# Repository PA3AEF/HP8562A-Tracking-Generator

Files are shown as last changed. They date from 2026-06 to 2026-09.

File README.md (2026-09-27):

# Tracking Generator for the HP 8562A/B Spectrum Analyzer  
**Reconstructing the Analyzer’s RF Sweep from Its Local Oscillator**
**A modular, analyzer‑synchronous architecture**

---

## What this project is

The HP 8562A/B spectrum analyzer does not include a tracking generator.  
However, it exposes enough of its internal LO system to build one externally.

This project implements a **modular, sweep‑synchronous Tracking Generator (TG)** that behaves as if it were a native part of the HP 8562A/B.  
It reconstructs the analyzer’s RF sweep using only:

- 1st LO Output (about 3.9–6.8 GHz)  
- LO Sweep Output (0–10 V, 0.5 V/GHz)  
- 10 MHz reference

The TG becomes a slave to the analyzer’s LO system and rebuilds the RF sweep in real time across multiple microwave bands.

---

## Why build a Tracking Generator for the HP 8562A/B?

The HP 8562A/B is a legendary instrument: fast, sensitive, and extremely stable.  
But without a tracking generator, it cannot perform:

- filter alignment  
- cavity tuning  
- antenna measurements  
- scalar network analysis  
- frequency response characterization  

This project fills that gap with a TG that follows the analyzer sweep exactly, using the analyzer’s own LO architecture.

---

## How the analyzer sweeps — and how the TG reconstructs the RF

The HP 8562A/B does not sweep an RF source.  
It sweeps its **first local oscillator** and mixes incoming signals down to a fixed IF.  
To cover 1 kHz–26 GHz, it uses **automatic harmonic mixing**, where each RF band uses a different harmonic of the LO:

| RF Band | Harmonic n | IF | LO Formula |
|---:|:---:|---:|---|
| 1 kHz–2.9 GHz | 1 | 3.9107 GHz | LO_SA = RF_SA + 3.9107 GHz |
| 2.75–6.46 GHz | 1 | 310.7 MHz | LO_SA = RF_SA + 0.3107 GHz |
| 5.86–13.0 GHz | 2 | 310.7 MHz | LO_SA = (RF_SA + 0.3107 GHz) / 2 |
| 12.4–19.7 GHz | 3 | 310.7 MHz | LO_SA = (RF_SA + 0.3107 GHz) / 3 |
| 19.1–26.0 GHz | 4 | 310.7 MHz | LO_SA = (RF_SA + 0.3107 GHz) / 4 |

For each band, the analyzer follows: `n * LO_SA = RF_SA + IF`

Because **n changes with band**, the analyzer LO becomes **non‑linear** with respect to the displayed frequency.

A tracking generator must compensate for this non‑linearity to stay aligned.

---

## How the TG reconstructs the analyzer RF

The TG uses the analyzer LO_SA (or a harmonic of it) as the primary LO and subtracts a fixed IF to recreate the analyzer’s RF:

```
RF_TG = (n * LO_SA) – IF_TG
```

Where:

- IF_TG = 310.7 MHz (fixed for all microwave TG modules)  
- n = analyzer harmonic mode for that band  

This yields:

- Base‑Band (n = 1):  
  RF_TG = LO_SA – 3.9107 GHz

- 6 cm (n = 1):  
  RF_TG = LO_SA – 0.3107 GHz

- 3 cm (n = 2):  
  RF_TG = (2 × LO_SA) – 0.3107 GHz

- 12 mm (n = 4, concept):  
  RF_TG = (4 × LO_SA) – 0.3107 GHz

This architecture reqires **no swept PLLs** in the microwave TG modules.  
Sweep coherence comes entirely from the analyzer LO.

---

## High‑level TG architecture

The TG system is composed of modular RF boards:

- **MCU board:**  
  Reads sweep voltage, computes RF_SA for calibration, programs PLLs

- **RF SA‑LO Distribution board:**  
  Conditions and splits the analyzer’s 1st LO to all TG modules

- **Base‑Band TG module:**  
  0–2.9 GHz (uses MAX2870)

- **6 cm TG module:**  
  4.4–6.4 GHz (LO_SA direct, IF_TG = 310.7 MHz)

- **3 cm TG module:**  
  9.5–11.5 GHz (LO_SA ×2, IF_TG = 310.7 MHz)

- **12 mm TG module (concept):**  
  22–26 GHz (LO_SA ×4, IF_TG = 310.7 MHz)

Conceptually:

```
Analyzer → LO Distribution → TG Modules → RF Outputs
Analyzer → 10 MHz → PLLs
Analyzer → V_sweep → MCU → Harmonic modules
```

Each TG module reconstructs the analyzer RF at its own band using a mixer‑based architecture.

---

## TG coverage limits

- **Implemented TG bands:**  
  - Base‑Band (0–2.9 GHz)  
  - 6 cm (4.4–6.4 GHz)  
  - 3 cm (9.5–11.5 GHz)

- **Conceptual / future TG bands:**  
  - 12 mm (22–26 GHz)

- **Analyzer coverage:**  
  - Up to 26 GHz with Option 026  
  - TG coverage currently ends at 11.5 GHz

---

## Repository structure

```
/docs/architecture
    01-tg-system-architecture.md
    02-lo-architecture.md
    03-analyser-lo-internals.md
    04-rf-sa-lo-distribution.md
    05-baseband-module.md
    06-6cm-module.md
    07-3cm-module.md
    08-12mm-module.md
/docs/architecture/images
    architecture diagrams
/firmware
    MCU firmware (Raspberry Pi Pico)
    overview
    images
/hardware/<module>
    schematics, layouts, BOMs, images
/mechanical
    enclosures, front panels
/usage
    calibration and measurement tools
```

---

## Status (Sep 27, 2026)

Checkout the [discussion section](https://github.com/PA3AEF/HP8562A-Tracking-Generator/discussions) for updates on the first results I have. 

- File: [example S21 3 cm lossy filter](./images/s21-3cm-lossy-filter.jpg)
- File: [example S11 3 cm pole filter](./images/s11-3cm-pole-filter.jpg)
- MCU board: 
  - concept tested OK, new PCB in development to accomodate new 10 MHz distribution architecture
  - firmware tested OK. Waiting for final PCB to start polish and publish
- LO Distribution: finished 
- Base‑Band module: finished  
- 3 cm module: proof of concept tested OK (tracking at 10 GHz with 2 GHz span)  
- 6 cm module: architecture defined  
- 12 mm module: conceptual design complete  

---

## License

MIT License.  
See `LICENSE` for details.

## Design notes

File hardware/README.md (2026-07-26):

# Hardware — TG Project

This directory contains all hardware designs for the modular Tracking Generator (TG).  
Each RF module is fully self‑contained with its own schematic, PCB if applicable, and data on on read-made building-blocks.

The hardware is organized into four primary modules:

- **Baseband Module (0–2.9 GHz)**
- **6 cm Module (4.4–6.4 GHz)**
- **3 cm Module (8.5–11.5 GHz)**
- **LO Module (Isolation and distribution of 1st LO from SA)**

All PCBs are designed in KiCad and stored in separate subdirectories.

---

## Directory Structure

Each module directory contains:

- **`schematic.pdf`** — complete schematic  
- **`pcb/`** — KiCad PCB files, 3D views, fabrication output  
- **`bom.csv`** — Bill of Materials  
- **`readme.md`** — module‑specific documentation (gain budget, design notes, test plan)

---

## Hardware Module Overview

### **Baseband Module (0–2.9 GHz)**
- IF chain from the HMC219 downconverter
- PLL at 3.9107 GHz  
- 3 GHz low‑pass filter  
- Pads, IF amplifier, SMA output  

### **6 cm Module (4.4–6.4 GHz)**
- HMC220 mixer  
- IF and RF amplification  
- Band‑pass filtering for 4–8 GHz  
- Purpose: upconversion for the 6 cm tracking generator band

### **3 cm Module (9.5–11.5 GHz)**
- HMC220 mixer 
- PLL at 310.7 MHz
- Band-pass filter at 310 MHz 
- High‑frequency RF amplifier (9–12 GHz)  
- Band‑pass filtering for 8–12 GHz  
- Purpose: upconversion for the 3 cm tracking generator band

### **Control Module**
- Raspberry Pi microcontroller
- Control of all circuitry, indicators, etc.
- Power provision for each band module (5-12V selectable) 
- Prper startup-shutdown sequence for band switching
- 10 MHz reference input buffering and distribution (SMA)
- SPI control for PLLs 

### **LO Module**
- Isolation of 1st LO output of analyser
- Braodband amplification of 1st LO output
- Distribution of 1st LO to band modules 

---

## Design Principles

- **Modular:** each RF module is electrically and mechanically independent  
- **SMA‑based:** all interconnects use SMA cables for clean, predictable RF paths  
- **Reproducible:** BOMs, schematics, and PCB files are fully documented  
- **RF‑optimized:** short signal paths, solid grounding, controlled impedance  
- **Measurable:** each module includes clear test points and a documented gain budget

---

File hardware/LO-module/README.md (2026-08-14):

# LO Module — External 1st LO Distribution

The LO Module takes the **1st LO output from the HP 8562A/B Spectrum Analyzer** and distributes it cleanly and at controlled power levels to all TG RF modules.  
The module provides isolation, optionally gain compensation, RF switching, and MCU‑based band selection.

---

## Purpose

- Accept the **external 1st LO** (3.9–6.8 GHz, ~16.5 dBm) from the HP8562A/B  
- Provide **3.5–7 GHz isolation** to protect the analyzer and stabilize the LO feed  
- Apply **~10 dB broadband gain** to compensate for PE42540 switch losses  
- Route the LO to **four isolated SMA outputs**  
- Allow **MCU‑controlled band selection** via PE4250/PE42540 RF switches  
- Deliver **~+16 dBm** per‑port LO drive for mixers in each TG band module

---

## Block Diagram

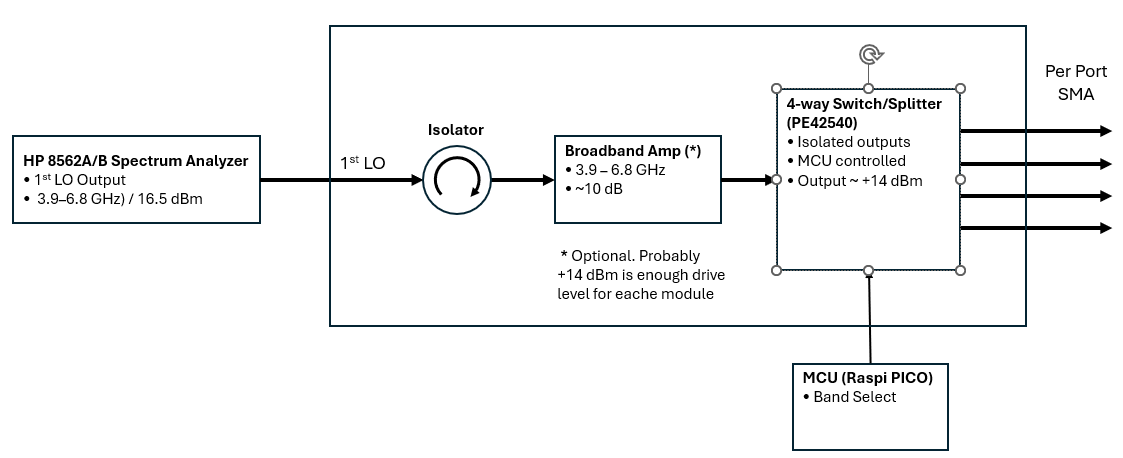
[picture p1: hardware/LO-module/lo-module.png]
TG system architecture


---

## LO Signal Path

### 1. 1st LO Input
- Source: HP 8562A/B Spectrum Analyzer  
- Frequency: **3.9–6.8 GHz**  
- Power: **~16.5 dBm**  
- Input is routed directly into the isolator to protect the analyzer and stabilize impedance.

### 2. Isolator (3.5–7 GHz)
- Ensures reverse isolation  
- Prevents reflections from the TG system  
- Provides a stable load to the analyzer’s LO output

**NOTE:** A broad amplifier can be used instead. It would give enough isolation too. 

### 3. Broadband Amplifier (~10 dB) (optional)
- Frequency range: **3.9–6.8 GHz**  
- Purpose: compensate insertion loss of RF switch  
- Ensures final per‑port LO level remains at **~+16 dBm**

**NOTE:** Various solutions can be used to create a 4-way switch/splitter. WIth the low-loss PE42540 it is not necesary

### 4. PE42540 4‑Way RF Switch/Splitter
- Provides **four isolated LO outputs**  
- MCU‑controlled switching  
- Low insertion loss  
- Output level per port: **~+16 dBm**

### 5. SMA Outputs
- One SMA per band module  
- Clean, isolated LO feed  
- Stable drive level for mixers

### 6. MCU Control (Raspberry Pi Pico)
- Controls PE42540  
- Selects active LO output path  
- Provides band‑select logic for TG modules

---

## Design Notes

- LO drive target: **~+16 dBm** at each SMA  
- Isolator ensures analyzer protection and stable LO impedance  
- Broadband amp compensates switch losses and maintains output power  
- PE42540 chosen for isolation and MCU‑controlled routing  
- Maintain short RF traces and controlled impedance routing

---

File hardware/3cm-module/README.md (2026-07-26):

# 3 cm Tracking Generator Module (9.5–11.5 GHz)

The 3 cm module is the harmonic‑mode RF upconversion stage of the Tracking Generator.  
It reconstructs the analyzer’s 9.5–11.5 GHz sweep by combining:

- the analyzer’s 1st LO (LO_SA = 4.905–5.905 GHz)  
- the analyzer’s internal IF = 310.7 MHz (harmonic 2 mode)  
- a TG‑generated IF_TG = 310.7 MHz from an ADF4351  
- a doubled version of the analyzer’s 1st LO (LO₂ = 9.81–11.81 GHz) for the HMC220 mixer

All frequencies remain coherent with the analyzer because they are derived from the analyzer’s 1st LO and 10 MHz reference.

---

## Harmonic‑mode coherence

In the 3 cm band, the HP 8562A/B uses **2× harmonic mixing** with an internal IF of **310.7 MHz**.

The analyzer’s 1st LO follows:  
`2 × LO_SA = RF_SA + 310.7 MHz`  →  `LO_SA = (RF_SA + 310.7 MHz) / 2`

For RF_SA = 9.5–11.5 GHz, this yields:  
`LO_SA = 4.905–5.905 GHz`

This is the actual LO range the 3 cm TG module must track.

---

## Why the LO must be doubled

The HMC220 mixer requires:

- IF port: DC–4 GHz  
- LO/RF ports: 5–12 GHz  

The analyzer’s 1st LO (4.905–5.905 GHz) is too low for the HMC220 LO port.  
Therefore, the TG uses a ×2 multipiler (HMC204): `LO₂ = 2 × LO_SA = 9.81–11.81 GHz`, fitting the mixer’s LO range.

---

## IF_TG generation (ADF4351)

The TG generates a fixed IF signal using the ADF4351: `IF_TG = 310.7 MHz`.  
The MCU programs the ADF4351 via SPI and maintains sweep coherence with the analyzer’s 10 MHz reference.
A Band Pass Filter at 310 MHz follows the ADF4351 to maintain signal purity. 

---

## Mixer output and TG coherence

The HMC220 mixer produces: `RF_TG = LO₂ – IF_TG = RF_SA`  
Substituting the ranges:  
LO₂ = 9.81–11.81 GHz, IF_TG = 310.7 MHz → RF_TG = 9.5–11.5 GHz.  
This exactly matches the analyzer’s displayed frequency.

---

## Module architecture and building blocks

### HMC204 Analyzer LO doubler
- Input: LO_SA = 4.905–5.905 GHz  
- Output: LO₂ = 9.81–11.81 GHz  
- Purpose: shift analzer LO into HMC220 LO range while maintaining sweep coherence

### ADF4351 IF_TG generator
- Output: 310.7 MHz (fixed)  
- MCU‑controlled and reference‑locked  
- Purpose: provide the IF offset needed to reconstruct RF_TG

**HFSS modeling results optimized for standard LC values:** 

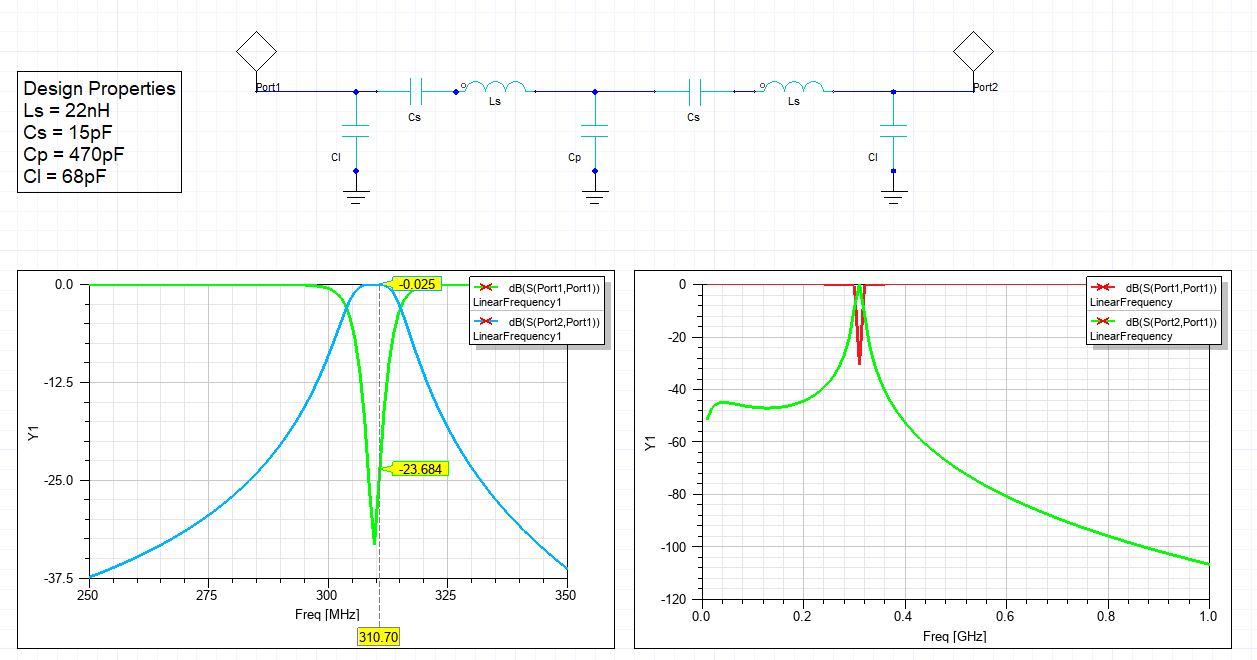
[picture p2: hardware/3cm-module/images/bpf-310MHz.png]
310 MHz BPF


### HMC220 mixer
- LO port: 9.81–11.81 GHz  
- IF port: 310.7 MHz  
- RF port: 9.5–11.5 GHz  
- Purpose: perform the upconversion that produces the 3 cm TG output

### Band‑pass filter (8–12 GHz)
- Removes LO₂ leakage, IF_TG leakage, and mixer images  
- Ensures only the 9.5–11.5 GHz band reaches the amplifier

Did not succeed yet in modeling a proper BPF so, for now a simple lowpass filter on 0.8mm FR4. 

**HFSS modeling results for a stepped impedance lowpass filter:** 

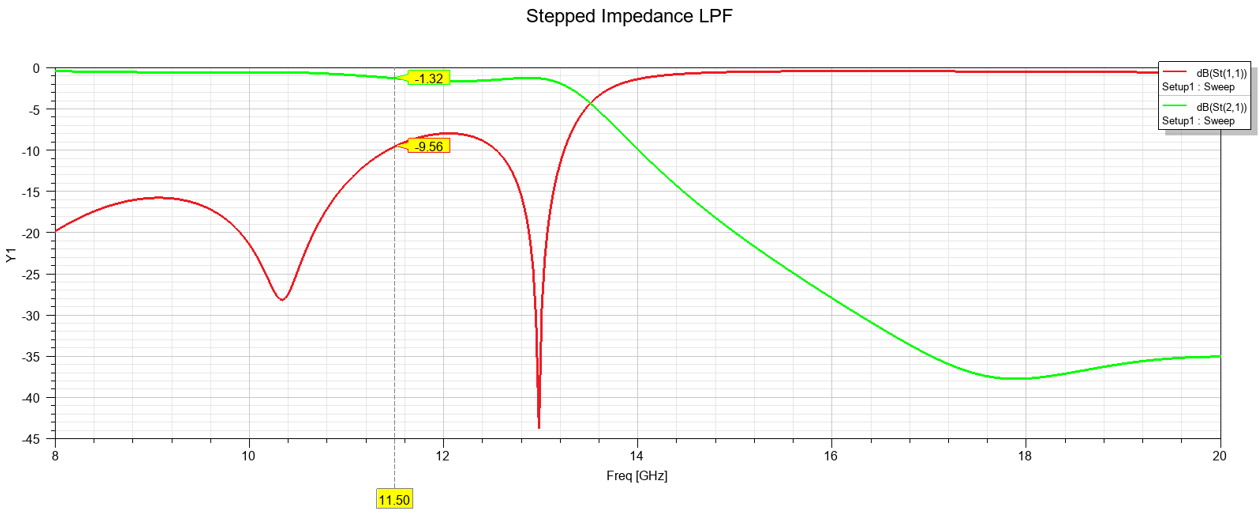
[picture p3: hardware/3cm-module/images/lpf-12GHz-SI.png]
12 GHz LPF stepped impedance


### RF gain stage + output pad
- Provides ~0 dBm output  
- Maintains linearity across the sweep  
- Ensures stable 50 Ω output at the TG output SMA connector

---

## Performance targets

### Frequency performance
- Output band: 9.5–11.5 GHz  
- Must track analyzer sweep exactly  
- Fast settling to follow analyzer sweep speed

### Amplitude performance
- Target output: ~0 dBm  
- Flatness corrected at system level  
- No compression across sweep

### Spectral purity
- Low LO₂ leakage  
- Low IF_TG leakage  
- Spurs dominated by ADF4351 + multiplier chain  
- Phase noise dominated by analyzer LO

### Implementation constraints
- RF layout suitable for >10 GHz  
- Isolation between LO₂, IF_TG, and RF paths  

---

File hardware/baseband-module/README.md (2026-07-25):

# Base‑Band Tracking Generator Module  
**(0–2.9 GHz fundamental‑mode section)**

The Base‑Band module generates the 0–2.9 GHz portion of the Tracking Generator output.  
It uses the analyzer’s 1st LO as the swept RF input and mixes it with a locally generated LO_TG to recreate the analyzer’s RF sweep at the TG output.

This module contains the **core RF building blocks** for fundamental‑mode operation:

- clean LO_TG generation  
- LO driver amplification  
- fundamental mixer  
- post‑mix filtering  
- output leveling  

All signals remain coherent with the analyzer because the MAX2870 locks to the analyzer’s 10 MHz reference.

---

## Module Overview

The Base‑Band module consists of the following RF chain:

1. **Analyzer 1st LO input from the LO Distribution module**  
2. **MAX2870 PLL generating LO_TG (fixed 3.9107 GHz)**  
3. **LO driver amplifier (20 dB gain)**  
4. **LO band‑pass filter + pad**  
5. **Fundamental mixer (HMC219)**  
6. **Low‑pass filter (DC–3 GHz)**  
7. **Output pad (level trim)**

Each block is described below.

---

## Building Blocks (LO_TG path)

### MAX2870 PLL / LO_TG Source
- Generates the fixed LO_TG required for fundamental mixing.  
- Locked to the analyzer’s 10 MHz reference for coherence.  
- Output level is low (programmable -4 dBm to +5 dBm) and requires external amplification.  
- Ready‑made MAX2870 modules with SPI and SMA connectors work well

---

### LO Driver Amplifier (3.9 GHz)
- Raises the MAX2870 output to proper mixer‑drive levels.  
- Provides stable gain and low added phase noise.  
- Offers isolation between the PLL and the mixer LO port.  
- A boxed 20 dB gain module with SMA I/O is ideal.

---

### LO Band‑Pass Filter (3.9107 GHz) + Pad
- Cleans up PLL and amplifier spurs.  
- Ensures a spectrally clean LO_TG at the mixer.  
- Final pad sets the LO level to ~13 dBm at the HMC219 LO pin.  
- Ready‑made BPF modules with SMA I/O work well, but DIY can perform equally well

---

## Mixer and Output Path

### Fundamental Mixer (HMC219)
- Core element of the Base‑Band module.  
- RF port: analyzer 1st LO (3.9–6.8 GHz)  
- LO port: LO_TG (~13 dBm)  
- IF/RF output: 0–2.9 GHz TG signal  
- Requires good grounding and shielding to minimize LO feedthrough.  
- Ready‑made boxed modules very much simplify construction.

---

### Low‑Pass Filter (DC–3 GHz)
- Removes mixer images and LO leakage.  
- Defines the usable Base‑Band TG output range.  
- Should have low insertion loss and strong stop‑band rejection.  
- DIY CNC‑boxed LPF is fine; ready‑made modules also work.
- Optional pad trims the output to 0 dBm.

**HFSS modeling results optimized for standard LC values:**
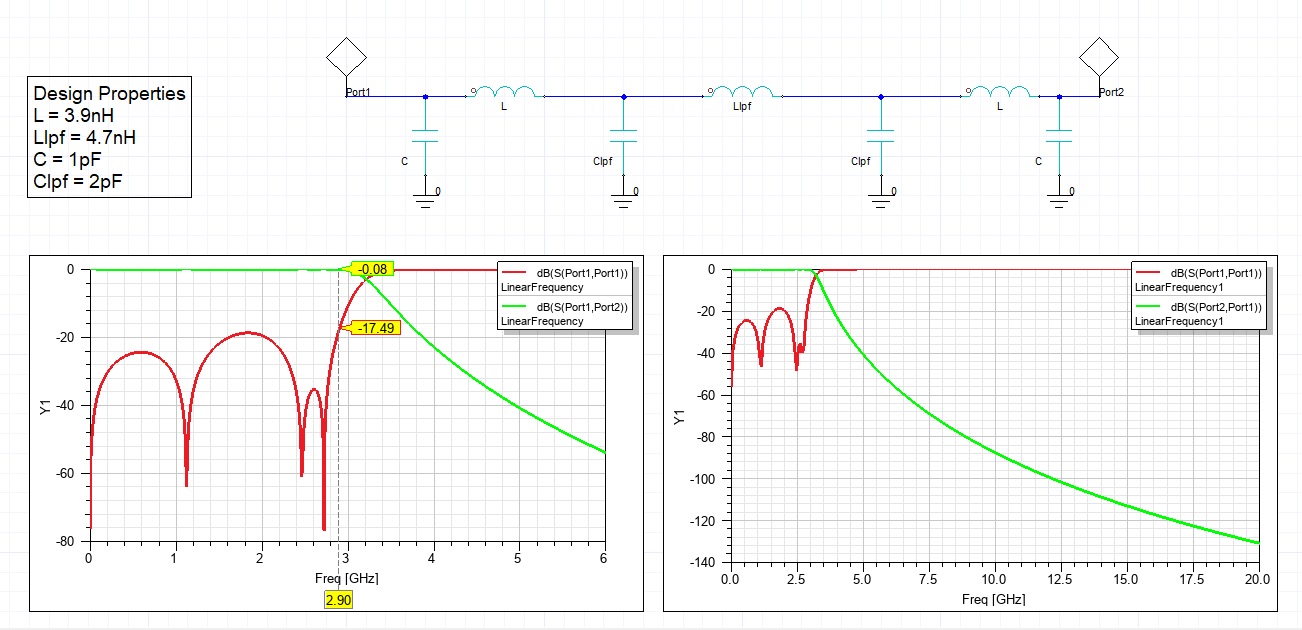
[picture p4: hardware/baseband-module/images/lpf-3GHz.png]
Low Pass Filter with Fc 3 GHz


Another solution was modeled using folded stepped impedance open subs after Makki et al. 

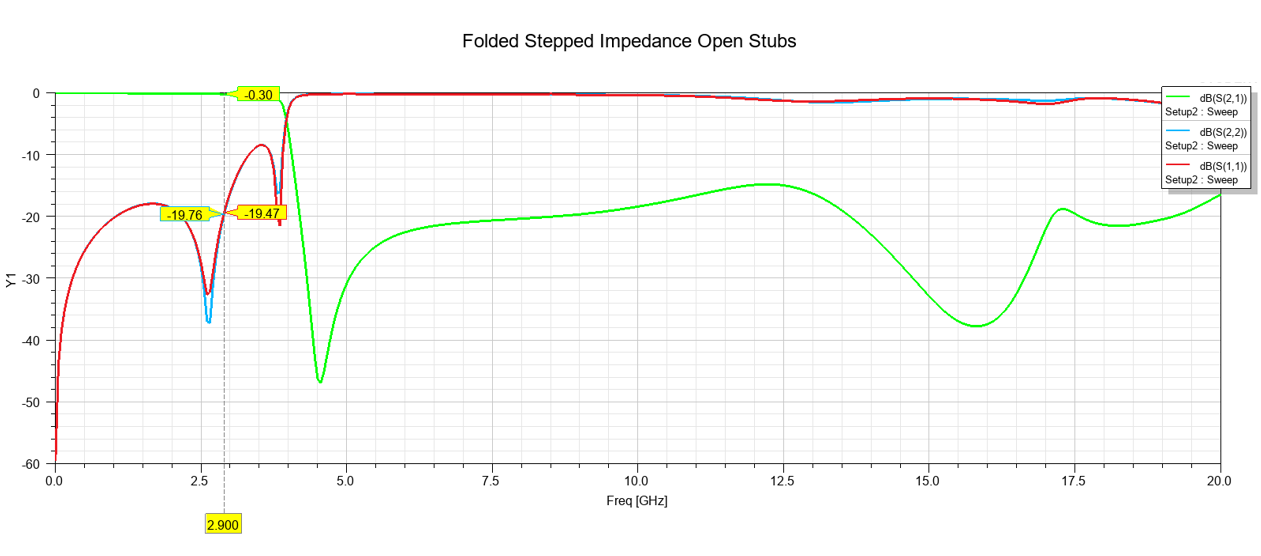
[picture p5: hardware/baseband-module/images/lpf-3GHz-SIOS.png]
Low Pass Filter with Fc 3 GHz on Microstrip


---

## Performance Goals

### Frequency Tracking
- Output range: 0–2.9 GHz  
- Must follow analyzer sweep exactly  
- Settling must match analyzer sweep speed

### Amplitude Performance
- Target output: ~0 dBm  
- Flatness corrected at system level  
- Avoid compression in the LO driver and mixer

### Spectral Cleanliness
- Low LO leakage  
- Low mixer images  
- Spurs dominated by PLL  
- Phase noise dominated by analyzer LO

### Implementation Notes
- RF‑clean routing up to 3 GHz  
- Strong isolation between LO_TG and RF paths  

---

## Summary

The Base‑Band module is straightforward once broken into functional blocks.  
Each block (PLL, LO driver, mixer, filters, pads) can be built and tested independently.
Many blocks are ready-made available.

---

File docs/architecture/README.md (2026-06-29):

# Documentation Index

---

## System Architecture

### 01 TG System Architecture  
File: [01-tg-system-architecture.md](./01-tg-system-architecture.md) 
High‑level description of the complete Tracking Generator system: module roles, signal flow, LO distribution, and control architecture.

---

## Local Oscillator Architecture

### 02 - LO Architecture  
File: [02-lo-architecture.md](./02-lo-architecture.md)
Detailed explanation of how all LOs are derived from the analyzer’s 1st LO and 10 MHz reference, including per‑band LO strategies.

---

## Analyser Local Oscillator Internals

### 03 - Analyser LO Internals
File: [03-analyser-lo-internals.md](./03-analyser-lo-internals.md)
Explain how the HP 8562A/B analyzer generates the 4.905–5.905 GHz 1st LO range used by the Tracking Generator.

---

## LO Distribution Hardware

### 04 - RF SA‑LO Distribution  
File: [04-rf-sa-lo-distribution.md](./04-rf-sa-lo-distribution.md)
Design and function of the LO distribution module that conditions, isolates, and splits the analyzer’s 1st LO to al TG modules.

---

## TG Modules

### 05 - Base‑Band TG Module (0–2.9 GHz)  
File: [05-base-band-module.md](./05-base-band-module.md)
Architecture and implementation of the fundamental‑mode TG module.

### 06 - 6 cm TG Module (4.4-6.4 GHz)  
File: [06-6cm-module.md](./06-6cm-module.md)
Architecture and implementation of the 6 cm harmonic‑mode TG module.

### 07 - 3 cm TG Module (9.5–11.5 GHz)  
File: [07-3cm-module.md](./07-3cm-module.md)
Architecture and implementation of the 3 cm harmonic‑mode TG module.

### 08 - 12 mm TG Module (concept)  
File: [08-12mm-module.md](./08-12mm-module.md)
Architecture and implementation of the 12 mm harmonic‑mode TG module.

---

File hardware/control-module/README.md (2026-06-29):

# Control Module — MCU and 10 MHz Reference Buffer (Hardware)

Compact hardware overview for the Control Module: power sequencing, protection, MCU host interfaces, and the low‑noise 10 MHz reference buffering and 1:4 distribution. Detailed hardware-level descriptions for the **10 MHz reference** and **MCU** are in separate documents (`docs/10MHz_reference.md`, `docs/mcu-hardware.md`). Firmware is covered elsewhere.

---

## Purpose

- Buffer and distribute an external **10 MHz reference** to **4 isolated outputs**  
- Provide MCU-host hardware: power, programming, debug, and physical control interfaces  
- Protect and condition reference and power inputs (ESD, TVS, reverse polarity)  
- Present SPI/UART/USB headers and status indicators for system integration

---

## Block Diagram

10 MHz Ref In → Input Protection → Low‑noise Buffer → 1:4 Splitter/Switch → Output Buffers → **4 × SMA REF OUT**  
Power In → Sequencing & Regulators → MCU + Peripherals  
MCU headers: SPI, UART, VRef, Switch, RF-Modules

---

## Hardware Interfaces

- **Reference Input**
  - **SMA** connector with input protection and level detect
  - DC blocking and optional AC coupling upstream of buffer
- **Reference Outputs**
  - **4 × SMA** buffered outputs, individually enabled
  - Target nominal level: **0 dBm** per output (see `docs/10MHz_reference.md`)
- **Control / Comms**
  - **SPI** header (MOSI, MISO, SCLK, CS, GND, Vcc) for downstream PLLs
  - **UART / USB** hardware interface for firmware connectivity
- **Power**
  - External DC input with reverse‑polarity protection
  - Onboard regulators with power‑good signals and sequencing
- **Indicators**
  - Power, module-select and lock detect fault LEDs at PCB headers

---

## Design Notes (Hardware Only)

- **Phase noise:** buffer chosen to add minimal phase noise; layout keeps RF ground continuous under RF chain.  
- **Isolation:** per‑output buffering prevents cross‑talk; outputs terminated and DC‑blocked.  
- **Protection:** input ESD, TVS, and surge protection on REF IN and power rails.  
- **Mechanical:** SMA connectors on PCB edge; keep digital switching components physically separated from RF path.  
- **EMC:** ferrite beads, common‑mode chokes, and local decoupling to reduce digital noise coupling into 10 MHz path.  
- **Test points:** RF amplitude, buffer bias, and power‑good nets exposed for bench verification.

---

## Connector / Pin Summary

- **REF IN:** SMA (10 MHz)  
- **REF OUT 1–4:** SMA buffered outputs  
- **SPI:** 6‑pin header (MOSI, MISO, SCLK, CS, GND, Vcc)  
- **UART/USB:** Micro‑USB or TTL UART header  
- **POWER:** Screw terminal or header;
- **Band Selection:** 3-pin header
- **LO Switch:** 3-pin header
- **RF Modules:** 3-pin and 2-pin headers 

---

## Control Module
 
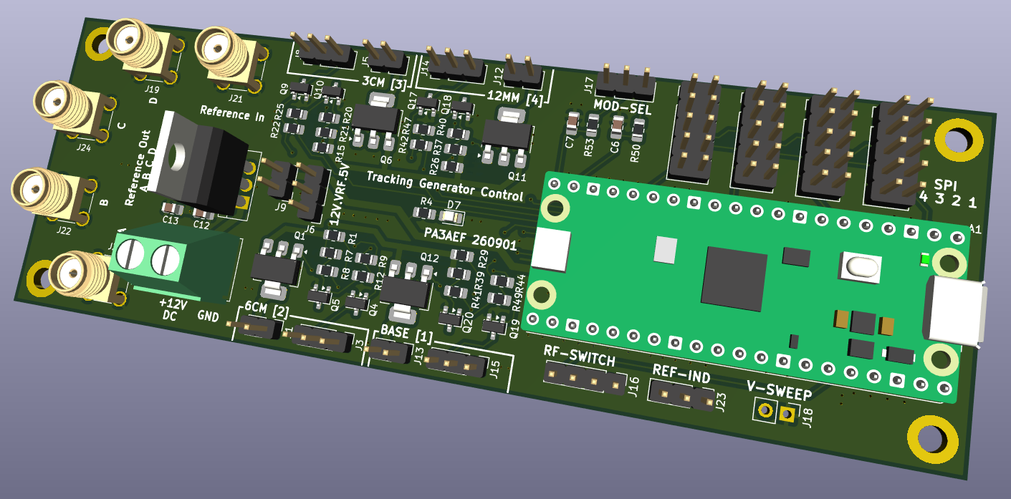
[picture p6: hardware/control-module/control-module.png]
Control Module populated PCB


---

## Documentation

Hardware detail references:  
- **`10MHz_reference.md`** — full schematic, BOM, and RF measurements  
- **`mcu-hardware.md`** — MCU pinout, power sequencing, and debug connectors  
- **`control-module`** — mechanical drawings and test fixtures

---

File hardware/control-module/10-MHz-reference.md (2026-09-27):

# 10 MHz Reference Fan‑Out

The 10 MHz reference distribution network provides a stable, low‑noise signal to multiple subsystems within the control module.  
This revision replaces the earlier op‑amp‑based buffer with a **broadband MMIC amplifier** to achieve higher gain, better impedance control, and improved RF integrity.

---

## Design Intent
The goal is to replicate a single precision 10 MHz reference into several identical outputs while maintaining:

- Consistent amplitude and phase across all outputs  
- True 50 Ω system compatibility  
- Minimal additive noise and distortion  
- Simple, robust implementation suitable for RF PCB layout  

---

## Functional Architecture

The circuit can be viewed as **four functional blocks**:

1. **Input Conditioning**  
   - The incoming 10 MHz reference is terminated and AC‑coupled into a broadband amplifier.  
   - The interface maintains 50 Ω impedance to prevent reflections and loading of the source.  
   - A small detection network monitors the presence of the reference signal and converts it into a DC logic level for indication.

2. **Amplification**  
   - A single MMIC amplifier provides sufficient gain to overcome splitter losses.  
   - The device operates linearly at 10 MHz, ensuring clean reproduction of the reference signal.  
   - Power‑supply filtering and decoupling maintain low noise and prevent modulation of the reference.

3. **Signal Distribution**  
   - The amplifier output feeds a passive multi‑way splitter.  
   - Each branch is impedance‑matched and AC‑coupled to its output connector.  
   - The topology ensures isolation between outputs and preserves amplitude balance.

4. **Reference‑Presence Indicator**  
   - A detector monitors the RF level at the amplifier output and generates a logic signal when the 10 MHz reference is present.  
   - This logic drives a **dual‑color LED** that provides immediate visual feedback:  
     - **Red** indicates that the module is powered but no reference signal is detected.  
     - **Green** indicates that the 10 MHz reference is active and within expected amplitude.  
   - The indicator circuit uses a simple envelope‑detection and transistor‑switching scheme to translate the RF presence into a DC control signal.

---

## Operational Behavior

When power is applied, the indicator initially lights **red**, confirming that the module is energized but awaiting a valid reference.  
As soon as the 10 MHz signal reaches nominal amplitude, the detector transitions to **green**, signaling that the reference is locked and distributed correctly.  
If the reference disappears or drops below threshold, the circuit automatically reverts to red, providing a clear visual cue of signal loss.

---

## Performance Characteristics
- **Gain Margin:** The amplifier compensates for splitter attenuation, maintaining nominal output levels.  
- **Isolation:** Passive resistive topology provides adequate separation between outputs for reference use.  
- **Noise Contribution:** The MMIC adds negligible phase noise compared to the master reference.  
- **Bandwidth:** The design remains stable and flat well beyond 10 MHz, ensuring predictable behavior.  
- **Power Supply:** Operates from a single low‑voltage rail with standard RF decoupling practices.

---

## Implementation Notes
- Short RF paths and continuous ground planes.  
- Via fencing around the amplifier region for stability.  
- Decoupling capacitors close to the device pins.  
- Maintain symmetry in the splitter layout to ensure equal path lengths.  
- AC‑couple all outputs to DC-protect downstream circuits.

---

## Summary
This MMIC‑based fan‑out architecture provides a clean, broadband, and impedance‑controlled distribution of the 10 MHz reference.  
It simplifies the design compared to op‑amp buffers, improves gain margin, and ensures reliable operation across all connected modules.

---

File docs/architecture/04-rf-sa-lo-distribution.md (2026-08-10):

# RF SA‑LO Distribution Module  
**Function:** Conditioning and distribution of the analyzer’s 1st LO  
**Input:** SA 1st LO (3.9–6.8 GHz, ~+16.5 dBm)  
**Outputs:** Four LO feeds to TG modules  
**Target Output Level:** +16 dBm per port (→ +13 dBm at mixer LO pins)

---

## Overview

The RF SA‑LO Distribution module receives the analyzer’s 1st LO and provides a clean, isolated, level‑controlled LO feed to all Tracking Generator modules.

Its responsibilities:

- Protect the analyzer LO port  
- Provide stable impedance and isolation  
- Amplify the LO to compensate for splitter loss  
- Split the LO into four well‑behaved outputs  
- Ensure each module can achieve **+13 dBm at the mixer LO pin**

This board forms the **central LO backbone** for the entire TG system.

---

## Frequency & level plan

### Input  
- SA 1st LO: 3.9–6.8 GHz  
- Typical level: +16.5 dBm  
- Sweep‑synchronous with analyzer RF

### Internal processing  
- Isolator stabilizes return loss and protects the analyzer (a 10dB gain-block would also give enough isolation) 
- Broadband amplifier restores headroom before splitting (probably not necessary with CMOS siwtch such as PE42540)
- Splitter (Wilkinson, relays or MMICs) provides isolation between TG modules  
- Per‑branch pads flatten response and set final level

### Output targets  
Each TG module receives:

- **LO OUT:** +16 dBm nominal  
- After on‑module pad/filter (~3 dB):  
  → **+13 dBm at mixer LO pin**

---

## Block diagram

SA LO distribution architecture

---

## Power budget (nominal)

| Stage | Gain/Loss | Level |
|:---|---:|---:|
| SA 1st LO | — | +16.5 dBm |
| Isolator | –0.5 dB | +16 dBm |
| 4-way split (PE42540) | -1.5 dB | +14.5 dBm |
| TG module LO input | — | +14.5 dBm |
| On‑module pad/filter | –3 dB | **+11 dBm at mixer LO pin** |

---

## Output ports

Four identical LO outputs:

- Base‑Band module  
- 6 cm module  
- 3 cm module  
- 12 mm module  

Each port includes:

- Isolation thru splitter  
- Per‑branch pad  
- 50 ohm matched SMA  
- +16 dBm nominal output

---

## Mechanical / layout notes

- Isolator close to TG input  
- Amplifier and splitter routes short and shielded  
- Clear labeling for all LO outputs  

---

## Future expansion

Designed to support:

- Additional TG modules  
- Higher‑frequency LO distribution  
- Optional per‑branch filtering  
- LO mute switching thru MCU

---

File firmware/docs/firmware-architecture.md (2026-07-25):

# Firmware Architecture HP8562A Tracking Generator

This document describes the modular firmware architecture used in the **HP8562A Tracking Generator** project.  
It complements the system‑level design documents in `/docs/architecture` and focuses on the internal structure, sequencing, and logic of the firmware modules.

---

## 1. Overview

The firmware controls the TG’s mixed‑PLL synthesizer system (MAX2870 + ADF4351), band‑switching logic, and RF routing.  
It is designed for clarity, reproducibility, and modularity, following a clean separation between hardware abstraction and signal‑chain logic.

### Key design goals
- Deterministic band‑switching sequence  
- Unified PLL programming interface  
- Operator‑friendly feedback and debug output  
- Safe RF transitions (no hot‑switching)  
- Extensible for future bands or PLL types  

---

## 2. Directory Structure

/firmware  
  src/  
   • Tracking_Generator.ino
   • pins.h
   • bands.h / bands.cpp
   • pll_max2870.h / pll_max2870.cpp  
   • pll_adf4351.h / pll_adf4351.cpp    
   • pll_control.h / pll_control.cpp  
   • pe42540.h / pe42540.cpp
   • ramp.h / ramp.cpp  
   • rotary.h / rotary.cpp  
   docs/  
   • firmware_architecture.md  

Each module has a single responsibility and can be tested independently.

---

## 3. Module Responsibilities

**pins.h** - Defines all GPIO assignments  
**bands.cpp** - Implements band table, state machine, and switching logic  
**pll_max2870.cpp / pll_adf4351.cpp** - Compute register sets for each PLL type  
**pll_control.cpp** - Holds static default register sets per band  
**pe42540.cpp** - Controls LO routing switch
**ramp.cpp** - Converts ramp ADC value to LO frequency  
**rotary.cpp** - Reads Gray‑code band selector  
**Tracking_Generator.ino** - Initializes modules and runs the control loop  

---

## 4. Band‑Switching Sequence

The firmware follows an eight‑step, RF‑safe switching sequence:

1. Disable old gain block (`PIN RFEN_xx LOW`)  
2. Disable old PLL (`PIN CE_xx LOW`)  
3. Switch LO path (PE42540)  
4. Enable new PLL (`PIN CE_xx HIGH`)  
5. Program PLL registers  
6. Wait for lock (`PIN LD_xx HIGH`)  
7. Enable new gain block (`PIN RFEN_xx HIGH`)  
8. New band active  

### Sequence Diagram  

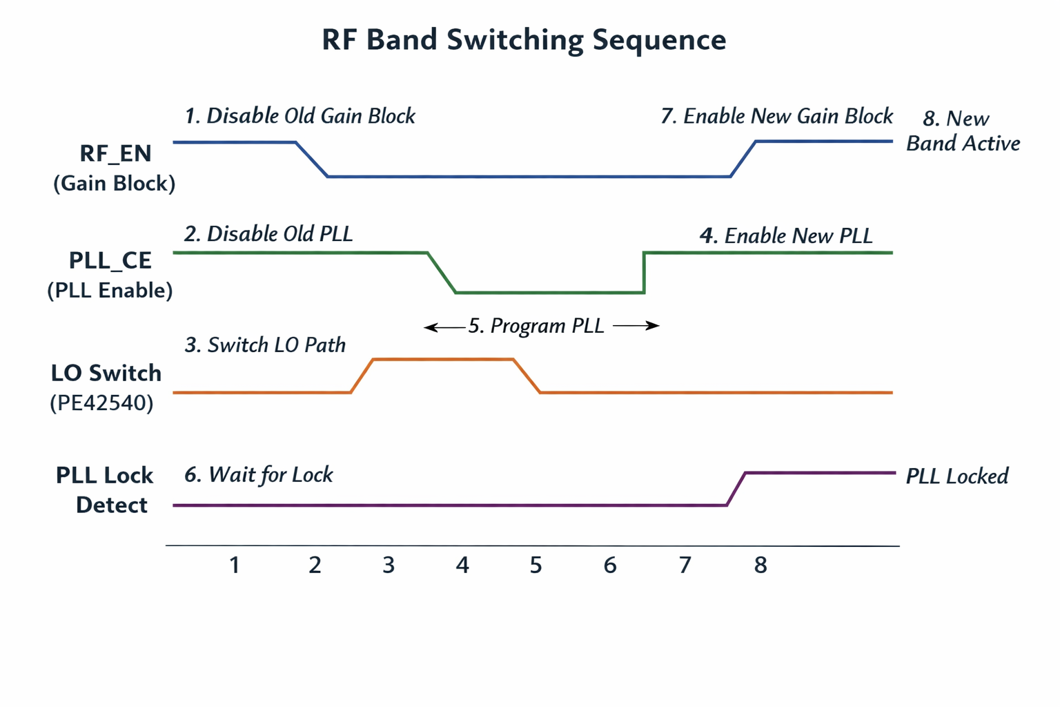
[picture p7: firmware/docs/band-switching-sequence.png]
Band switching sequence


### Timing Diagram  

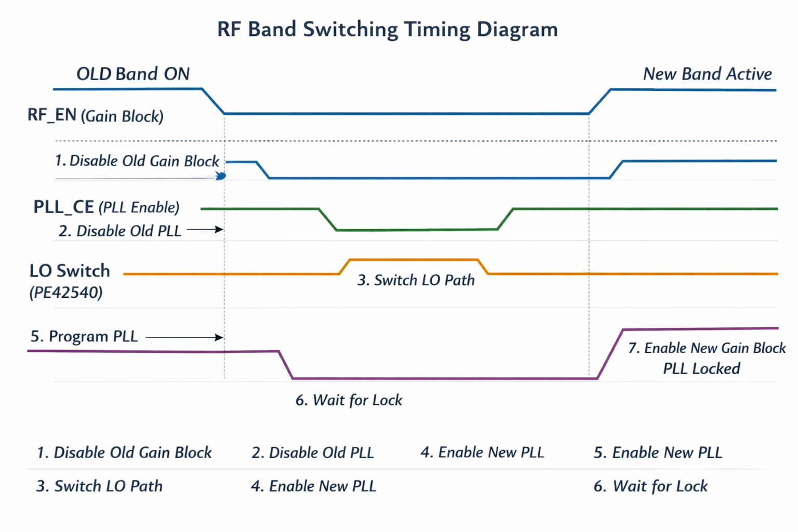
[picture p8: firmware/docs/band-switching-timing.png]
Band switching timing


These diagrams illustrate the relative timing of RF_EN, PLL_CE, LO Switch, and PLL Lock Detect signals.

---

## 5. Safety and Timing Considerations

- RF_EN is always turned off before any LO or PLL transition  
- PLL_CE is toggled only when RF_EN is low  
- PE42540 switching occurs with no RF present  
- PLL lock time is verified before enabling RF output  
- Typical delays:  
  • CE‑to‑SPI start: 500 µs  
  • SPI burst: ~100 µs  
  • Lock wait: 5–10 ms (band‑dependent)  

---

## 6. Build and Deployment

- Platform: Raspberry Pi Pico (RP2040)  
- Toolchain: Arduino RP2040 Core  
- SPI speed: 1 MHz (safe for MAX2870/ADF4351)  
- Serial debug: 115200 baud  
- Upload via USB using Arduino IDE or CLI  

---

## 7. References

- MAX2870 Datasheet  
- ADF4351 Datasheet  
- PE42540 Datasheet  

---

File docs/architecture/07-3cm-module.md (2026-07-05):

# 3 cm Tracking Generator Module  
**RF Output:** 9.5–11.5 GHz (2 GHz span)  
**Harmonic Mode:** n = 2  
**Mixer Core:** HMC220  
**TG IF LO:** ADF4351 (fixed 310.7 MHz)  
**SA LO Path:** Doubled analyzer LO (9.81–11.81 GHz)

---

## Overview

The 3 cm module generates a tracking‑synchronous RF output in the 9.5–11.5 GHz range.  
It operates in the analyzer’s **2× harmonic mixing mode** and derives all timing from:

- **V_sweep**  
- **Analyzer LO_SA** (fundamental synthesizer output)  
- **10 MHz reference**

The module uses:

- A **doubled analyzer LO** as the high‑frequency LO for the HMC220  
- A **fixed‑frequency ADF4351** at 310.7 MHz as the IF LO  
- An HMC220 mixer to produce the final RF output via the difference product

This module forms the primary **X‑band TG path** in the system.

---

## Frequency plan

### Analyzer‑derived quantities  
`RF_SA = 2 * V_sweep`  
`IF_SA = 310.7 MHz`  
`n = 2`

### Analyzer LO (fundamental synthesizer output)  
Harmonic‑mode relation:  
`IF_SA = | 2 * LO_SA – RF_SA |`

Analyzer uses the **high‑side** solution:  
`LO_SA = (RF_SA + 310.7 MHz) / 2`

For RF_SA = 9.5–11.5 GHz:  
`LO_SA = 4.905–5.905 GHz`

This is the **actual analyzer LO** delivered to the TG distribution board.

---

### Doubled LO for HMC220 LO port  
`LO_2 = 2 * LO_SA`  → `9.8107–11.8107 GHz`

This is the **high‑frequency LO** applied to the HMC220 LO port.

---

### TG IF LO (ADF4351)  
Mixer uses:  
`RF_TG = LO_2 – IF_TG = RF_SA`

Since `LO_2 = RF_SA + 310.7 MHz`,  
we require:  
`IF_TG = 310.7 MHz` (constant)

Thus the ADF4351 runs at a **fixed 310.7 MHz**, simplifying control and calibration.

---

## Block diagram

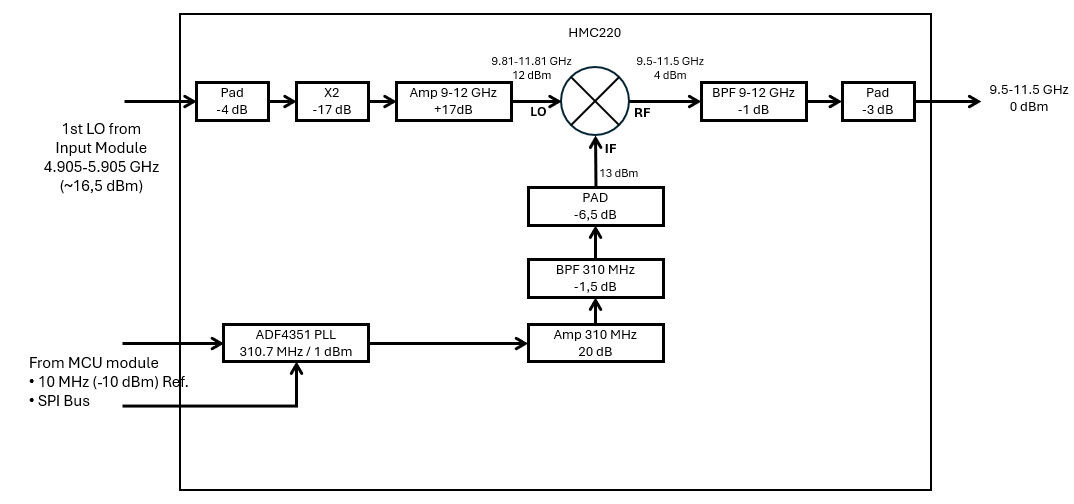
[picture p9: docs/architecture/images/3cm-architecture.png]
3cm TG architecture


```

---

## Power budget (nominal)

| Stage                         | Frequency             | ΔdB     | Level   |
|-------------------------------|----------------------:|--------:|--------:|
| **LO path**                   |                       |         |         |
| SA LO output                  | 4.905–5.905 GHz       |   0 dB  | +16 dBm |
| LO isolator                   | 4.905–5.905 GHz       |  –1 dB  | +15 dBm |
| LO Switch (PE42540)           | 4.905–5.905 GHz       |  -1 dB  | +14 dBm
| LO doubler input              | 4.905–5.905 GHz       |   0 dB  | +14 dBm |
| LO doubler (HMC204)           | 9.81–11.81 GHz        | –17 dB  |  –3 dBm |
| LO amplifier                  | 9.81–11.81 GHz        | +15 dB  | +12 dBm |
| LO at mixer LO port           | 9.81–11.81 GHz        |   0 dB  | +13 dBm |
|                               |                       |         |         |
| **IF path**                   |                       |         |         |
| ADF4351 IF output             | 310.7 MHz             |   0 dB  |  +2 dBm |
| IF filter                     | 310.7 MHz             |  –1 dB  |  +1 dBm |
| IF amplifier                  | 310.7 MHz             | +20 dB  | +21 dBm |
| IF pad (to mixer IF port)     | 310.7 MHz             | –14 dB  |  +7 dBm |
| IF at mixer IF port           | 310.7 MHz             |   0 dB  |  +7 dBm |
|                               |                       |         |         |
| **RF path**                   |                       |         |         |
| Mixer RF out (nominal)        | 9.5–11.5 GHz          |  –8 dB  |  ~5 dBm |
| RF pad / EQ                   | 9.5–11.5 GHz          |  –5 dB  |   0 dBm |
| RF output (SMA)               | 9.5–11.5 GHz          |   0 dB  |   0 dBm |

Levels are nominal and must be trimmed with pads and EQ for flatness over the 2 GHz span.

---

## Control architecture

### Inputs to MCU  
- Band select switch

### MCU responsibilities  
- Program ADF4351 to **fixed 310.7 MHz**  
- Manage LO enable/mute  
- Provide calibration hooks

### SPI layout  
- Shared SPI bus  
- Dedicated CS for ADF4351  
- PLL lock‑detect GPIO

---

## Calibration notes

- Amplitude flatness corrected via output pad/EQ  
- `LO_2` level set by fixed‑gain amplifier  
- ADF4351 spur performance acceptable due to low IF offset  
- No IF sweep required (fixed 310.7 MHz simplifies calibration)

---

## Mechanical / layout notes

- Doubler → LO amp → HMC220 LO path should be short and shielded  
- Good isolation between `LO_2` and RF output  
- ADF4351 IF routing requires clean 50 Ω but is not microwave‑critical  
- Fine‑tune pads for correct levels at `LO_2`, `IF_TG`, and `RF_TG`  

---

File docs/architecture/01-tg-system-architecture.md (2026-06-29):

# Tracking Generator System Architecture  
**Modules:** LO Distribution, Base‑Band, 3 cm, 6 cm (future), 12 mm (future)  
**Coherence Sources:** Analyzer 1st LO, Analyzer 10 MHz reference  
**Architecture:** Distributed mixer‑based TG with per‑band modules  
**Control:** Central MCU (Raspberry Pi Pico)

---

## Overview

The Tracking Generator (TG) system is a modular, analyzer‑synchronous signal source covering:

- **Base‑Band:** 0–2.9 GHz  
- **6 cm:** 4.4-6.4 GHz 
- **3 cm:** 9.5–11.5 GHz  
- **12 mm:** 23-25 Ghz (future)  

All TG modules derive their timing and frequency coherence from the **spectrum analyzer’s internal LO system**, ensuring that the TG output always tracks the analyzer sweep.

Two analyzer signals form the foundation:

- **1st LO** (swept, 3.9–6.8 GHz)  
- **10 MHz reference** (system clock)

The TG system uses these to generate all required LOs for each band.

---

## System‑level signal flow

The TG system is composed of six boards:

1. **MCU (Raspberry Pi Pico)**  
2. **RF SA‑LO Distribution Module**  
3. **Base‑Band TG Module**  
4. **6 cm TG Module**  
5. **3 cm TG Module**  
6. **12 mm TG Module** (future)

The analyzer’s 1st LO enters the system through the **LO Distribution Module**, which conditions and splits it to all TG modules.  
Each TG module then generates its own internal LO(s) and performs mixing to reconstruct the analyzer RF at its target band.

---

## LO architecture summary

### Analyzer 1st LO  
- 3.9–6.8 GHz  
- Sweep‑synchronous  
- Distributed to all TG modules at +16 dBm

### Analyzer 10 MHz reference  
- Shared reference for all PLLs  
- Ensures long‑term coherence

### Base‑Band module  
- Internal IF LO: MAX2870 at 3.9107 GHz (fixed)  
- Mixer: HMC219  
- Output: 0–2.9 GHz

### 6 cm module  
- Internal IF LO: ADF4351 at 310.7 MHz (fixed)  
- Mixer: HMC219
- Output: 4.4-6.4 GHz

### 3 cm module  
- High‑frequency LO: Doubled analyzer LO (8.94–10.28 GHz)  
- Internal IF LO: ADF4351 at 310.7 MHz (fixed)  
- Mixer: HMC220  
- Output: 9.5–11.5 GHz

### 12 mm module (future)  
- Will require higher‑order multiplication  
- Output expected in 23-25 GHz region

---

## Block diagram

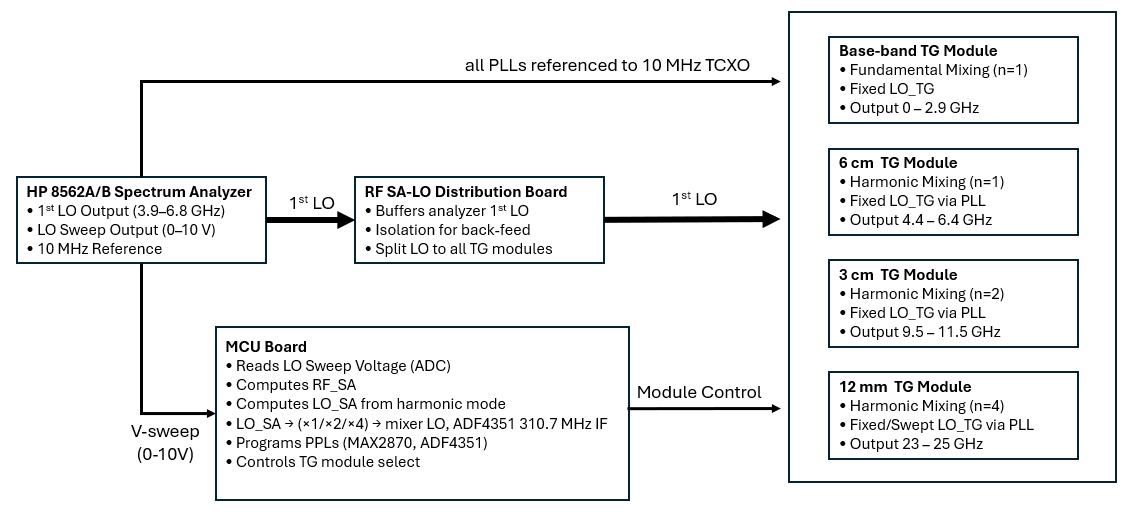
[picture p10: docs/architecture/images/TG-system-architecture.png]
TG system architecture


---

## Power distribution & LO levels

| Path | Level | Notes |
|---|---:|---|
| Analyzer 1st LO → Distribution | +16.5 dBm | Raw analyzer output |
| Distribution → TG modules | +16 dBm | After isolator, amp, splitter, pad |
| TG module LO input | +13 dBm | After on‑module pad/filter |
| TG mixer LO input | +13 dBm | After LO chain |
| Output | 0 dBm | After filters, amp, pad|

All levels are chosen to meet mixer LO drive requirements and maintain isolation.

---

## Control architecture

### MCU responsibilities  
- Program MAX2870 (Base‑Band)  
- Program ADF4351 (6 cm and 3 cm)  
- Compute sweep‑dependent IF if needed 
- Manage LO enable/mute  
- Monitor PLL lock‑detect  
- Handle band selection  

### Shared resources  
- SPI bus shared across all PLLs  
- Dedicated chip‑select per module  
- 10 MHz reference distributed to all PLLs  
- Optional GPIO for LO mute and module enable

---

## Calibration architecture

Each module supports:

- Output level trimming via pads  
- LO drive trimming  
- Mixer conversion‑loss compensation  

System‑level calibration ensures:

- Consistent output level across bands  
- Flatness across each module’s span  
- Coherent phase relationship with analyzer LO

---

## Mechanical / layout considerations

- Analyser LO input at front panel (Cabinet below SA)
- LO Distribution module placed closest to analyzer LO input  
- TG modules arranged to minimize LO crosstalk  
- Shielding around mixers, doublers, and LO amplifiers  
- Consistent grounding across all modules  
- SMA connectors clearly labeled by band  

---

## Future expansion

The architecture is designed to scale to:

- Additional TG bands (e.g. modular RF front-ends with MCU band-descriptor table for LO range, step size, level, etc.) 
- Higher‑order multipliers (e.g. multiplier blocks as seperate modules with additional filters while keeping the PLLs at a comfortable range)
- Optional LO monitoring ports (e.g. directional couplers on LO lines for calibration hooks in the MCU) 
- Optional TG output leveling loops (e.g. per-band detector with digital step attenuators) 
- Optional digital predistortion for flatness correction

All highly ambitious but no roadblocks in the architecture for possible future developmenst . 

---

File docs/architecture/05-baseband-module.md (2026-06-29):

# Base‑Band Tracking Generator Module  
**RF Output:** 0–2.9 GHz  
**Mixer Core:** HMC219  
**TG LO:** MAX2870 at fixed 3.9107 GHz  
**Reference:** 10 MHz from spectrum analyzer  
**Sweep Source:** Analyzer 1st LO

---

## Overview

The Base‑Band module generates a tracking‑synchronous RF output from 0–2.9 GHz.  
It is used for:

- IF chains up to S‑band  
- Wideband filters  
- General‑purpose stimulus-response measurments in the 0–2.9 GHz range

The module uses:

- The analyzer’s 1st LO as the swept input  
- A fixed MAX2870 PLL at 3.9107 GHz  
- An HMC219 mixer  
- A 3 GHz low‑pass filter and output pad

The mixer’s difference product reconstructs the analyzer RF at base‑band.

---

## Frequency plan

### Analyzer RF  
`RF_SA = 0–2.9 GHz`

### Analyzer 1st LO  
`LO_SA = RF_SA + IF_1`  with `IF_1 = 3.9107 GHz`

So:  
`LO_SA = 3.9107–6.8107 GHz`

### TG LO (MAX2870)  
The MAX2870 is programmed once at power‑up:  
`LO_TG = 3.9107 GHz`

### Mixer relationship  
HMC219 ports:

- RF port: analyzer 1st LO  
- LO port: fixed 3.9107 GHz  
- IF port: TG output (0–2.9 GHz)

Mixer output:  
`IF_TG = LO_SA – LO_TG = RF_SA`

Thus the TG output equals the analyzer RF.

---

## Block diagram

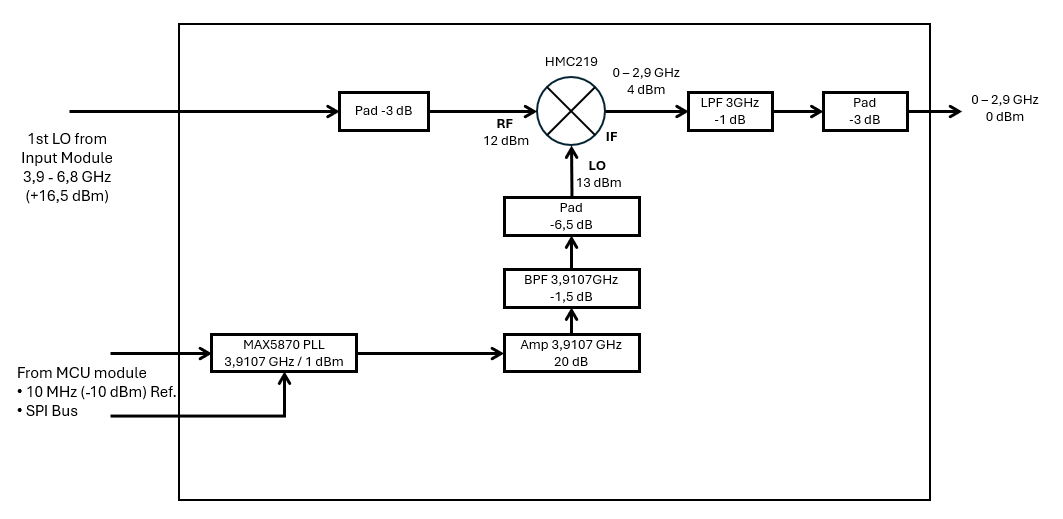
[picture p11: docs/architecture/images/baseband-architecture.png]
Base‑Band TG architecture


---

## Power budget (nominal)

| Stage | Frequency | ΔdB | Level |
|---|---:|---:|---:|
| **Analyzer LO → Mixer RF** | | | |
| SA 1st LO | 3.9–6.8 GHz | 0 dB  | +16.5 dBm|
| Isolator | 3.9–6.8 GHz |  -0.5 dB| +16.0 dBm|
| RF pad | 3.9–6.8 GHz |  –1 dB  | +15 dBm|
| Misc. losses (routing, etc.) | 3.9–6.8 GHz |  –1 dB  | +14 dBm  |
| LO at HMC219 RF port | 3.9–6.8 GHz | 0 dB  | +13 dBm  |
| | | | |
| **TG LO → Mixer LO** | | | |
| MAX2870 output | 3.9107 GHz | 0 dB  |  +1 dBm  |
| LO amplifier | 3.9107 GHz | +20 dB  | +21 dBm  |
| BPF | 3.9107 GHz |  –1.5 dB| +19.5 dBm|
| LO pad | 3.9107 GHz |  –6.5 dB| +13 dBm  |
| LO at HMC219 LO‑pin | 3.9107 GHz | 0 dB  | +13 dBm  |
| | | | |
| **Mixer IF → TG output** | | | |
| HMC219 IF‑output | 0–3 GHz | 0 dB  |  ~+4 dBm |
| LPF 3 GHz | 0–3 GHz |  –1 dB  |  +3 dBm  |
| Output pad | 0–3 GHz |  –3 dB  | 0 dBm  |
| TG output (SMA) | 0–3 GHz | 0 dB  | 0 dBm  |

---

## Control architecture

- MAX2870 uses the analyzer’s 10 MHz reference  
- SPI control from Raspberry Pi Pico (MCU)
- LO is fixed; no sweep‑depedent tuning necessary 
- MCU handles LO enable/mute and lock‑detect

---

## Mechanical / layout notes

- 3.9107 GHz LO chain short and shielded  
- Good isolation between high‑level LO and the 0–2.9 GHz output  
- Fine‑tune pads for correct levels at:  
  - SA 1st LO input  
  - MAX2870 LO chain  
  - HMC219 RF/LO/IF ports  
  - Final output  
- 3 GHz LPF ensures suppression of LO feedthrough and mixer images

---

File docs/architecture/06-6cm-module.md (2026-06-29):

# 6 cm Tracking Generator Module  
**RF Output:** 4.4–6.4 GHz (2 GHz span)  
**Harmonic Mode:** n = 1  
**Mixer Core:** HMC219
**TG IF LO:** ADF4351 (fixed 310.7 MHz)  
**SA LO Path:** Analyzer LO_SA (4.7107–6.7107 GHz)

---

## Overview

The 6 cm module generates a tracking‑synchronous RF output in the 4.4–6.4 GHz range.  
It operates in the analyzer’s **fundamental mixing mode (n = 1)** and derives all timing from:

- **V_sweep**  
- **Analyzer LO_SA** (fundamental synthesizer output)  
- **10 MHz reference**

The module uses:

- The **analyzer LO_SA directly** as the mixer LO  
- A **fixed‑frequency ADF4351** at 310.7 MHz as the IF LO  
- An HMC219/HMC220 mixer to produce the final RF output via the difference product

This module forms the primary **C‑band TG path** in the system.

---

## Frequency plan

### Analyzer‑derived quantities  
`RF_SA = 2 * V_sweep`  
`IF_SA = 310.7 MHz`  
`n = 1`

### Analyzer LO (fundamental synthesizer output)  
Harmonic‑mode relation:  
`IF_SA = | LO_SA – RF_SA |`

Analyzer uses the **high‑side** solution:  
`LO_SA = RF_SA + 0.3107 GHz`

Zero‑span measurements confirm:  
`LO_SA = 4.7107–6.7107 GHz`

This is the **actual analyzer LO** delivered to the TG distribution board.

---

### Mixer LO (direct analyzer LO)  
The mixer LO port receives:  
`LO_SA = 4.7107–6.7107 GHz`

This range is compatible with the HMC219 LO port.

---

### TG IF LO (ADF4351)  
Mixer uses:  
`RF_TG = LO_SA – IF_TG = RF_SA`

Since `LO_SA = RF_SA + 310.7 MHz`, we require: `IF_TG = 310.7 MHz` (constant)

Thus the ADF4351 runs at a **fixed 310.7 MHz**, simplifying control and calibration.

---

## Block diagram

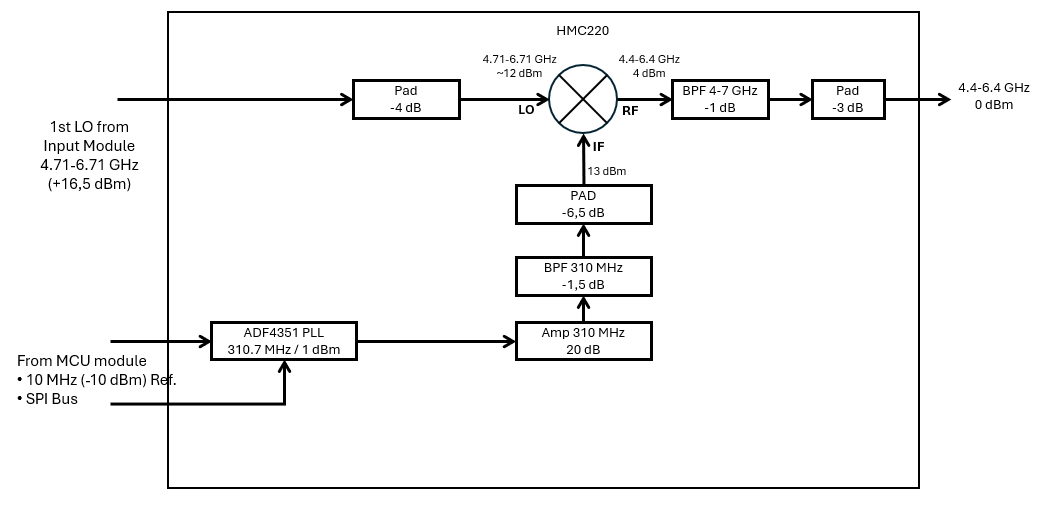
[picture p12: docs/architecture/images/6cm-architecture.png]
6cm TG architecture


---

## Power budget (nominal)

| Stage | Frequency | ΔdB | Level |
|---|---:|---:|---:|
| **LO path** | | | |
| SA LO output | 4.71–6.71 GHz | 0 dB | +16 dBm |
| LO isolator | 4.71–6.71 GHz |  –1 dB | +15 dBm |
| LO pad / buffer input | 4.71–6.71 GHz |  –2 dB | +13 dBm |
| LO at mixer LO port | 4.71–6.71 GHz | 0 dB | +13 dBm |
| Mixer LO‑to‑RF isolation  | 4.4–6.4 GHz |  — | (spec)  |
| | | | |
| **IF path** | | | |
| ADF4351 IF output | 310.7 MHz | 0 dB |  +2 dBm |
| IF filter | 310.7 MHz |  –1 dB |  +1 dBm |
| IF amplifier | 310.7 MHz | +20 dB | +21 dBm |
| IF pad (to mixer IF port) | 310.7 MHz | –14 dB |  +7 dBm |
| IF at mixer IF port | 310.7 MHz | 0 dB |  +7 dBm |
| | | | |
| **RF path** | | | |
| Mixer RF out (nominal) | 4.4–6.4 GHz |  –8 dB |  ~5 dBm |
| RF pad / EQ | 4.4–6.4 GHz |  –5 dB | 0 dBm |
| RF output (SMA) | 4.4–6.4 GHz | 0 dB | 0 dBm |

Levels are nominal and must be trimmd with pads and EQ for flatness over the 2 GHz span.

---

## Control architecture

### Inputs to MCU  
- Band select switch

### MCU responsibilities  
- Program ADF4351 to **fixed 310.7 MHz**  
- Manage LO enable/mute  
- Provide calibration hooks

### SPI layout  
- Shared SPI bus  
- Dedicated CS for ADF4351  
- PLL lock‑detect GPIO

---

## Calibration notes

- Amplitude flatness corrected via output pad/EQ  
- LO_SA level set by fixed‑gain buffer  
- ADF4351 spur performance acceptable due to low IF offset  
- No IF sweep required (fixed 310.7 MHz simplifies calibration)

---

## Mechanical / layout notes

- LO_SA → mixer LO path short and shielded  
- Good isolation between LO_SA and RF output  
- ADF4351 IF routing requires clean 50 Ω but is not microwave‑critical  
- Fine‑tune pads for correct levels at `LO_SA`, `IF_TG`, and `RF_TG`  

---

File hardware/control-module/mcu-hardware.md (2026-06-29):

# Control Module — MCU Hardware (Raspberry Pi Pico 2)

The MCU Module hosts the **Raspberry Pi Pico 2**, providing system control, SPI fan‑out, power‑good monitoring, and hardware‑level interfacing to all RF Modules. It exposes USB for host communication and SWD for programming/debug.  
Detailed schematics and electrical notes are in:  
- **`docs/mcu-hardware.md`**  
- **`docs/10MHz_reference.md`** (for the reference buffer subsystem)

---

## Purpose

- Provide a stable hardware platform for system control  
- Interface with RF Modules via **SPI**, **GPIO**, and fault/status lines  
- Offer **USB** as the sole host interface  
- Provide **SWD** for programming and debugging  
- Implement power‑good sensing and system‑level monitoring  

---

## Block Diagram

Power In → Protection → Regulators → **Pico 2**  
Pico 2 → SPI Header → RF Modules  
Pico 2 → USB → Host  
Pico 2 → SWD → Programming / Debug  
Pico 2 → Status LEDs

---

## Hardware Interfaces

### SPI Bus
- Pico 2 as SPI master  
- MOSI, MISO, SCLK, CS lines routed to a 6‑pin header  
- Series resistors for signal integrity  
- Optional per‑module chip‑select expansion

### USB (Host Interface)
- USB‑C or Micro‑USB connector (depending on PCB revision)  
- ESD protection on D+/D−  
- USB provides data only; power comes from main DC input  

### SWD (Programming / Debug)
- 3‑pin or 4‑pin SWD header (SWDIO, SWCLK, GND, optional 3V3)  
- Reset pin accessible via test pad  
- Suitable for production programming and field debugging  

### Power
- External DC input with reverse‑polarity protection  
- Local regulators for 5 V → 3.3 V  
- Power‑good signal routed to Pico 2  
- Decoupling around MCU supply pins  

### Status & Fault Indicators
- Power LED  
- Reference‑present LED (from reference buffer module)  
- Fault LED per module (basically Lock-Detect) driven by Pico 2  

---

## Design Notes (Hardware)

- **Noise isolation:**  
  Pico 2 digital switching kept physically separated from the 10 MHz reference path; ground stitching and ferrites reduce coupling.

- **Signal integrity:**  
  SPI traces length‑matched; series damping resistors on high‑speed lines.

- **Protection:**  
  TVS diodes on USB, ESD diodes on GPIO headers, reverse‑polarity MOSFET on power input.

- **Mechanical:**  
  USB connector and SWD header placed at board edge for easy access.

---

## Connector Summary

- **SPI Header:** MOSI, MISO, SCLK, CS, GND, Vcc  
- **USB:** USB‑C or Micro‑USB (data only)  
- **SWD:** 3‑ or 4‑pin programming header  
- **Power Input:** Screw terminal or pin-header  
- **Status LEDs:** Power, Reference, Fault (No Lock)  

---

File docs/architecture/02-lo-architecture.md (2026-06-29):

# LO Architecture  
**Sources:** Analyzer 1st LO, Analyzer 10 MHz reference  
**Internal LOs:** MAX2870 (Base‑Band), ADF4351 (3 cm), future 6 cm / 12 mm  
**Distribution:** Central RF SA‑LO Distribution module 
**Modes:** Fundamental mixing (Base‑Band), 2× harmonic mixing (3 cm), future bands

---

## Overview

The Tracking Generator system derives all timing and frequency coherence from the spectrum analyzer’s internal LO system.  
Two analyzer signals form the foundation:

- 1st LO (swept, ~2.9–6.8 GHz synthesizer output)  
- 10 MHz reference (system clock)

The TG system uses these to generate:

- Base‑Band LO (fixed 3.9107 GHz)  
- 3 and 6 cm IF LO (ADF4351, fixed 310.7 MHz)  
- 3 cm high‑frequency LO (doubled analyzer LO)  
- Future 12 mm LOs

All TG moduls remain phase‑coherent with the analyzer because every LO path ultimately derives from the analyzer’s 1st LO and 10 MHz reference.

---

## LO sources

### Analyzer 1st LO  
- Synthesizer range: 2.9–6.8 GHz  
- Delivered to TG as the fundamental LO_SA, used by all TG modules  
- **Effective LO_SA range depends on analyzer band and harmonic mode:**  
  - Base‑Band (0–2.9 GHz): harmonic 1, IF = 3.9107 GHz  
  - Mid‑band (2.75–6.46 GHz): harmonic 1, IF = 310.7 MHz 
    - 6 cm (4.4-6.4 GHz): harmonic 1, IF = 310.7 MHz → LO_SA = 4.710–6.710 GHz
  - High-band (5.86-13 GHz): harmonic 2, IF = 310.7 MHz
    - 3 cm (5.86–13 GHz): harmonic 2, IF = 310.7 MHz → LO_SA = 4.905–5.905 GHz
  - High-band-2 (12.4-19.7) GHz): harmonic 3, IF = 310.7 MHz
  - High-band-3 (9.5-11.5 GHz): harmonic 4, IF = 310.7 MHz
    - 12 mm (23–25 GHz): harmonic 4, IF = 310.7 MHz → LO_SA = 5.827–6.327 GHz
- Level: ~+16.5 dBm  
- Sweep‑synchronous  
- Defines the TG output frequency for all modules  
- For detailed internal LO generation, see **Analyzer LO Internals (3 cm Band)**

---

## LO distribution

The analyzer 1st LO enters the system through the RF SA‑LO Distribution Module, which performs:

- Input isolation  
- Broadband amplification  
- Signal splitting (Wilkinson, relays, or MMIC)  

Each TG module receives:

- LO IN: +16 dBm nominal  
- After on‑module pad/filter: ~+13 dBm at mixer input

This ensures consistent LO drive for all mixers (HMC219, HMC220, future devices).

---

# How the analyzer generates LO_SA in the 3 cm band

The HP 8562A/B uses **harmonic mixing mode n = 2** with a fixed IF of 310.7 MHz for the 5.86–13 GHz band.  
The internal first‑conversion relationship is:

`IF_SA = | 2 × LO_SA – RF_SA |`

Analyzer uses the high‑side solution:

`LO_SA = (RF_SA + 310.7 MHz) / 2`

For RF_SA = 9.5–11.5 GHz:

- LO_SA_min = 4.905 GHz  
- LO_SA_max = 5.905 GHz  

Thus the analyzer’s synthesizer output (the LO delivered to the TG distribution board) runs from:

**LO_SA = 4.905–5.905 GHz**

Because the TG derives all of its internal LOs from:

- the analyzer’s 1st LO (LO_SA = 4.905–5.905 GHz)  
- the analyzer’s 10 MHz reference  

every TG output is inherently phase‑coherent with the analyzer’s sweep.

---

# Harmonic‑mode coherence between analyzer and TG

The HP 8562A/B uses two mixing modes relevant to the TG:

- Fundamental mixing for the Base‑Band TG range (0–2.9 GHz)  
- **2× harmonic mixing** for the 3 cm TG range (9.5–11.5 GHz)

In the 3 cm band, the effective relationship between RF_SA and the synthesizer LO_SA is:

`LO_SA = (RF_SA + 310.7 MHz) / 2`

The TG then:

- doubles LO_SA to `LO_2 = 2 × LO_SA = RF_SA + 310.7 MHz`  
- uses a fixed IF_TG = 310.7 MHz  
- produces `RF_TG = LO_2 – IF_TG = RF_SA`

This ensures that the 3 cm TG output is coherent with the analyzer’s displayed frequency.

---

## LO usage per module

### Base‑Band module  
- Uses analyzer 1st LO as RF input  
- Uses MAX2870 (fixed 3.9107 GHz) as LO input  
- Mixer output: `RF_TG = LO_SA – LO_TG = RF_SA`  
- Produces 0–2.9 GHz TG output

### 6 cm module (future)  
- Uses analyzer 1st LO (LO_SA = 4.710–6.710 GHz) 
- Direct LO (4.710–6.710 GHz) → HMC220 LO port  
- ADF4351 generates fixed `IF_TG = 310.7 MHz`  
- Mixer output: `RF_TG = LO_2 – IF_TG = RF_SA`  
- Produces 4.4-6.4 GHz TG output

### 3 cm module  
- Uses analyzer 1st LO (LO_SA = 4.905–5.905 GHz) as input to doubler  
- Doubled LO: `LO_2 = 9.8107–11.8107 GHz` → HMC220 LO port  
- ADF4351 generates fixed `IF_TG = 310.7 MHz`  
- Mixer output: `RF_TG = LO_2 – IF_TG = RF_SA`  
- Produces 9.5–11.5 GHz TG output

### 12 mm module (future)  
- Similar architecture to 3 cm but at higher LO frequencies  
- May require:  
  - ×3 or ×4 multiplication  
  - High‑frequency gain blocks  
  - Tight shielding and isolation

---

## Reference Selection: 10 MHz vs. 300 MHz

The analyzer provides two possible reference signals:  
- **10 MHz TCXO** (primary timebase)  
- **300 MHz PLL output** (derived from the 10 MHz)

For the TG architecture, the **10 MHz reference is preferred**.

### Why 10 MHz is the correct choice
- The 10 MHz TCXO is the analyzer’s **master clock**.  
- The 300 MHz signal is generated by a **PLL locked to this 10 MHz**, so it carries **extra phase noise and spurs**.  
- MAX2870 and ADF4351 both accept low‑frequency references directly and internally divide as needed.  
- Using 300 MHz would require dividing it down anyway, giving **no benefit** and **worse noise**.  
- Locking to 10 MHz keeps the TG **coherent** with the analyzer, including when the analyzer is locked to an **external 10 MHz reference**.

Therfore, all TG PLLs use the analyzer’s **10 MHz TCXO** as their reference.  
It is cleaner, simpler, and guarantees long‑term coherence with the analyzer’s LO system.

---

## Power budget (Generic)

| Path | Stage | Level |
|---|---|---:|
| Analyzer LO → Distribution | Input | +16.5 dBm |
| Distribution → TG modules | After pads | +16 dBm |
| TG module LO input | On‑module pad/filter | +13 dBm |
| Base‑Band MAX2870 LO | After chain  | +13 dBm |
| 3 cm Doubled LO | After LO amp | +7 dBm  |
| 3 cm IF LO (ADF4351) | Direct | 0 dBm |

Levels may vary slightly per module but remain withjin mixer LO drive requirements.

---

## Control architecture

- All PLLs (MAX2870, ADF4351, future devices) lock to the analyzer’s 10 MHz reference  
- MCU programs:  
  - MAX2870 (Base‑Band)  
  - ADF4351 (3 cm)  
  - Future PLLs  
- MCU handles:  
  - LO enable/mute  
  - Lock‑detect monitoring
  - 10 MHz reference monitoring  
  - Sweep‑dependent IF calculations (Base‑Band only)  
  - Band selection

---

## Mechanical / layout notes

- LO distribution is short and well‑shielded  
- High isolation between LO paths and TG RF outputs    
- Consistent grounding across all TG modules  

---

## Future expansion

The LO architecture is designed to scale to:

- 12 mm TG module
- Higher‑order multipliers  
- Additional PLLs  
- Optional LO mute switching  
- Optional LO monitoring ports

The analyzer’s 1st LO and 10 MHz reference remain the single point of coherence for the entire TG system.

---

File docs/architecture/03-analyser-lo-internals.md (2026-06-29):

# Analyzer LO Internals (3 cm Band)  
**Purpose:** Explain how the HP 8562A/B analyzer generates the 4.905–5.905 GHz 1st LO range used by the Tracking Generator.

---

## Overview

In the 3 cm band (5.86–13 GHz), the HP 8562A/B operates in **harmonic mixing mode n = 2** and uses a **fixed first IF of 310.7 MHz**.  
Bands 1–4 (including 3 cm) use a **double‑conversion architecture**:

- **First conversion:** RF → 310.7 MHz  
- **Final conversion:** 310.7 MHz → 10.7 MHz  

The TG locks onto the analyzer’s **fundamental synthesizer output LO_SA**, which runs from **4.905–5.905 GHz** for RF_SA = 9.5–11.5 GHz.

This LO_SA range is derived from the harmonic‑mode equation:

**IF_SA = | 2 × LO_SA – RF_SA |**,  with **IF_SA = 310.7 MHz**.

The analyzer uses the **high‑side** solution: **LO_SA = (RF_SA + 310.7 MHz) / 2**

---

## Internal signal flow

1. **RF_SA (9.5–11.5 GHz)** enters the **Dual Mixer (A8)**.  
2. The analyzer’s **LO_synth** (4.905–5.905 GHz) is **doubled** internally to produce **2 × LO_synth = 9.81–11.81 GHz**.  
3. The first mixer down‑converts RF_SA to the **first IF = 310.7 MHz** (harmonic mode n = 2).  
4. The 310.7 MHz IF passes through the **Second Converter (A13)**, but **bypasses its mixer** (Bands 1–4 do not use the second conversion).  
5. The **Third Converter (A15)** performs the **final conversion** from 310.7 MHz to the **final IF = 10.7 MHz**, which feeds the display chain.

So according to the HP service manual:

> “Bands 1 through 4 use double conversion…  
> A Dual Mixer down‑converts the RF input to a first IF of 310.7 MHz…  
> The second and final conversion occurs in the third converter… producing the final 10.7 MHz IF.”

---

## Frequency relationships

### First conversion  
`IF_SA = | 2 * LO_SA – RF_SA |`

Analyzer uses the **high‑side** branch:

`2 * LO_SA = RF_SA + 310.7 MHz`  
`LO_SA = (RF_SA + 310.7 MHz) / 2`

### For RF_SA = 9.5–11.5 GHz  
- LO_SA_min = (9.5 + 0.3107) / 2 = **4.905 GHz**  
- LO_SA_max = (11.5 + 0.3107) / 2 = **5.905 GHz**

Thus the analyzer’s synthesizer output (LO_SA) runs from:

**LO_SA = 4.905–5.905 GHz**

This is the LO range distributed to the TG.

---

## Summary table

| Parameter | Symbol | Value / Range | Notes |
|---|---|---:|---|
| Displayed RF band | **RF_SA** | 9.5–11.5 GHz | Analyzer 3 cm band |
| First IF | **IF_SA** | 310.7 MHz | Fixed internal IF |
| Synthesizer output | **LO_SA** | 4.905–5.905 GHz | TG reference |
| Effective 1st LO | **LO_2** | 9.81–11.81 GHz | 2 × LO_SA |
| Final IF | **IF_display** | 10.7 MHz | Display IF |

---

## Integration with TG

The TG uses this LO_SA range to maintain coherence:

- Doubled LO:  
  **LO_2 = 2 × LO_SA = 9.8107–11.8107 GHz**  
- IF_TG (ADF4351):  
  **IF_TG = 310.7 MHz** (fixed)  
- Mixer output:  
  **RF_TG = LO_2 – IF_TG = RF_SA**

This ensures perfect frequency tracking between analyzer and TG.

---

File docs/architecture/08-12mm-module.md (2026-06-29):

# 12 mm Tracking Generator Module (concept)  
**RF Output:** 23.0–25.0 GHz (option band, includes 24.048 GHz amateur)  
**Harmonic Mode:** n = 4  
**Mixer Core:** mm‑wave mixer (22–26 GHz class)  
**TG IF LO:** ADF4351 (fixed 310.7 MHz)  
**SA LO Path:** Quadrupled analyzer LO (≈22.3–26.3 GHz)

---

## Overview

The 12 mm module is a **conceptual future TG path** extending coherent tracking into the 23–25 GHz option band.  
It operates in the analyzer’s **4× harmonic mixing mode** and derives all timing from:

- **Analyzer LO_SA** (fundamental synthesizer output)  
- **10 MHz reference**

The module uses:

- A **×4 LO chain** derived from the analyzer LO_SA as the mm‑wave LO  
- A **fixed‑frequency ADF4351** at 310.7 MHz as the IF LO  
- A mm‑wave mixer to produce the final RF output via the difference product

The 24.048 GHz amateur allocation lies inside this TG band.

---

## Frequency plan

### Analyzer‑derived quantities  
`RF_SA = 2 * V_sweep`  
`IF_SA = 310.7 MHz`  
`n = 4`

### Analyzer LO (fundamental synthesizer output)  

Harmonic‑mode relation:  
`IF_SA = | 4 * LO_SA – RF_SA |`

Analyzer uses the **high‑side** solution:  
`LO_SA = (RF_SA + 0.3107 GHz) / 4`

For RF_SA = 22.0–26.0 GHz:

- `LO_SA,min = (23.0 + 0.3107) / 4 ≈ 5.8277 GHz`  
- `LO_SA,max = (25.0 + 0.3107) / 4 ≈ 6.3277 GHz`

So the analyzer LO delivered to the TG is:

- **LO_SA ≈ 5.82–6.32 GHz**

At the 12 mm amateur allocation (24.048 GHz):

- `LO_SA ≈ (24.048 + 0.3107) / 4 ≈ 6.0897 GHz`

---

### Quadrupled LO for mm‑wave mixer LO port  

We choose:

`LO_4 = 4 * LO_SA = RF_SA + 0.3107 GHz`

So for RF_SA = 22.0–26.0 GHz:

- `LO_4 ≈ 22.3107–26.3107 GHz`

This is the **mm‑wave LO** applied to the mixer LO port.

---

### TG IF LO (ADF4351)  

Mixer uses:  
`RF_TG = LO_4 – IF_TG = RF_SA`

Since `LO_4 = RF_SA + 310.7 MHz`,  
we require:  
`IF_TG = 310.7 MHz` (constant)

Thus the ADF4351 again runs at a **fixed 310.7 MHz**, same control model as 6 cm and 3 cm.

---

## Block diagram

12mm TG architecture

---

## Power budget (nominal, 12 mm module – concept)

Same assumptions as before, but with updated frequency ranges:

```
## Power budget (nominal, 12 mm module – concept)

| Stage                              | Frequency               | ΔdB     | Level   |
|------------------------------------|------------------------:|--------:|--------:|
| **LO path**                        |                         |         |         |
| SA LO output                       | 5.58–6.58 GHz           |   0 dB  | +16 dBm |
| LO isolator                        | 5.58–6.58 GHz           |  –1 dB  | +15 dBm |
| ×2 multiplier #1 input             | 5.58–6.58 GHz           |   0 dB  | +15 dBm |
| ×2 multiplier #1 (conv. –15 dB)    | 11.16–13.16 GHz         | –15 dB  |   0 dBm |
| LO amp #1                          | 11.16–13.16 GHz         | +15 dB  | +15 dBm |
| ×2 multiplier #2 input             | 11.16–13.16 GHz         |   0 dB  | +15 dBm |
| ×2 multiplier #2 (conv. –15 dB)    | 22.3–26.3 GHz           | –15 dB  |   0 dBm |
| LO amp #2                          | 22.3–26.3 GHz           | +15 dB  | +15 dBm |
| LO pad to mixer LO port            | 22.3–26.3 GHz           |  –2 dB  | +13 dBm |
| LO at mixer LO port                | 22.3–26.3 GHz           |   0 dB  | +13 dBm |
|                                    |                         |         |         |
| **IF path**                        |                         |         |         |
| ADF4351 IF output                  | 310.7 MHz               |   0 dB  |  +2 dBm |
| IF filter                          | 310.7 MHz               |  –1 dB  |  +1 dBm |
| IF amplifier                       | 310.7 MHz               | +20 dB  | +21 dBm |
| IF pad (to mixer IF port)          | 310.7 MHz               | –14 dB  |  +7 dBm |
| IF at mixer IF port                | 310.7 MHz               |   0 dB  |  +7 dBm |
|                                    |                         |         |         |
| **RF path**                        |                         |         |         |
| Mixer RF out (nominal, conv. –8 dB)| 22.0–26.0 GHz           |  –8 dB  |  ~5 dBm |
| RF pad / EQ                        | 22.0–26.0 GHz           |  –5 dB  |   0 dBm |
| RF output (SMA / waveguide launch) | 22.0–26.0 GHz           |   0 dB  |   0 dBm |
```

**NOTE:** These are **design targets**, not commitments. Real parts will move the numbers a bit.

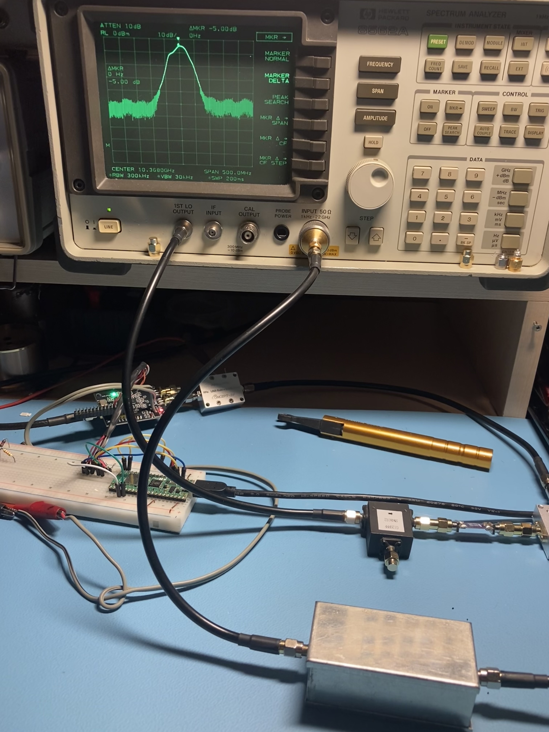
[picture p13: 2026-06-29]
images/s21-3cm-lossy-filter.jpg

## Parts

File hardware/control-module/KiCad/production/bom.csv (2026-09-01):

Designator | Footprint | Quantity | Value | LCSC Part #
A1 | RaspberryPi_Pico_Common_THT | 1 | RaspberryPi_Pico
C1, C11, C12, C14, C15, C16, C17, C18, C19, C3, C4, C5, C6, C7 | 0805 | 14 | 100nF
C10 | 0805 | 1 | 47uF
C13 | 0805 | 1 | 10uF
C2 | 0805 | 1 | 330nF
C8 | 0805 | 1 | 1pF
C9 | 0805 | 1 | 1nF
D6 | D_SMA | 1 | 1N4001
D7 | 0805 | 1 | LED
D8 | SOT-23 | 1 | BAT54S
J1, J12, J13, J5, J9 | PinHeader_1x02_P2.54mm_Vertical | 5 | Conn_01x02
J10, J11, J4, J7 | PinHeader_2x05_P2.54mm_Vertical | 4 | Conn_02x05_Odd_Even
J14, J15, J17, J23, J3, J6, J8 | PinHeader_1x03_P2.54mm_Vertical | 7 | Conn_01x03
J16 | PinHeader_1x04_P2.54mm_Vertical | 1 | Conn_01x04
J19, J20, J21, J22, J24 | SMA_Amphenol_901-144_Vertical | 5 | Conn_Coaxial
J2 | Screw terminal 3 pin | 1 | SCREW_TERMINAL
L1 | 1206 | 1 | RFC
Q1, Q11, Q12, Q6 | SOT-223-3_TabPin2 | 4 | ZXMP4A16G
Q10, Q13, Q14, Q15, Q16, Q17, Q18, Q19, Q2, Q20, Q22, Q3, Q4, Q5, Q7, Q8, Q9 | SOT-23 | 17 | MMBTA14
Q21 | SOT-23 | 1 | MMBT3904
Q23 | SOT-23 | 1 | BC857
R1, R12, R15, R18, R21, R22, R25, R26, R29, R32, R33, R40, R41, R42, R44, R47, R49, R5, R61, R62, R8, R9 | 0805 | 22 | 10K
R10, R11, R19, R23, R24, R34, R36, R43, R45, R46, R48, R6 | 0805 | 12 | 100K
R13, R14 | 0805 | 2 | 0R
R16, R17, R2, R27, R28, R3, R30, R31 | 0805 | 8 | **
R20, R37, R39, R7 | 0805 | 4 | 68K
R35, R38, R50, R53 | 0805 | 4 | 100R
R4, R55, R64, R65 | 0805 | 4 | 3K3
R56 | 0805 | 1 | 8k2
R57 | 0805 | 1 | 47K
R58, R60, R63, R67, R68 | 0805 | 5 | 39R
R59 | 0805 | 1 | 33R
R66 | 0805 | 1 | 49R9
U1 | TO-220-3_Vertical | 1 | LM7805_TO220
U2 | MSA_1 | 1 | MAR-6+

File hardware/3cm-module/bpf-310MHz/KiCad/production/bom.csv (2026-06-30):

Designator | Footprint | Quantity | Value | LCSC Part #
C1, C2 | 0805 | 2 | 15pF
C3, C5 | 0805 | 2 | 68pF
C4 | 0805 | 1 | 470pF
L1, L2 | 0805 | 2 | 22nH

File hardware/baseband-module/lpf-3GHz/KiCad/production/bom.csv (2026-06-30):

Designator | Footprint | Quantity | Value | LCSC Part #
C1, C2, C3, C4, C5, C6 | 0805 | 6 | 1pF
C7, C8 | 0805 | 2 | 0pF
L1, L3 | 0805 | 2 | 3n9
L2 | 0805 | 1 | 4n7

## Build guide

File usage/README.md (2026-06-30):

# Usage

This folder will hold some instructions to operate the Tracking Generator using the HP8562A Spectrum Analyzer

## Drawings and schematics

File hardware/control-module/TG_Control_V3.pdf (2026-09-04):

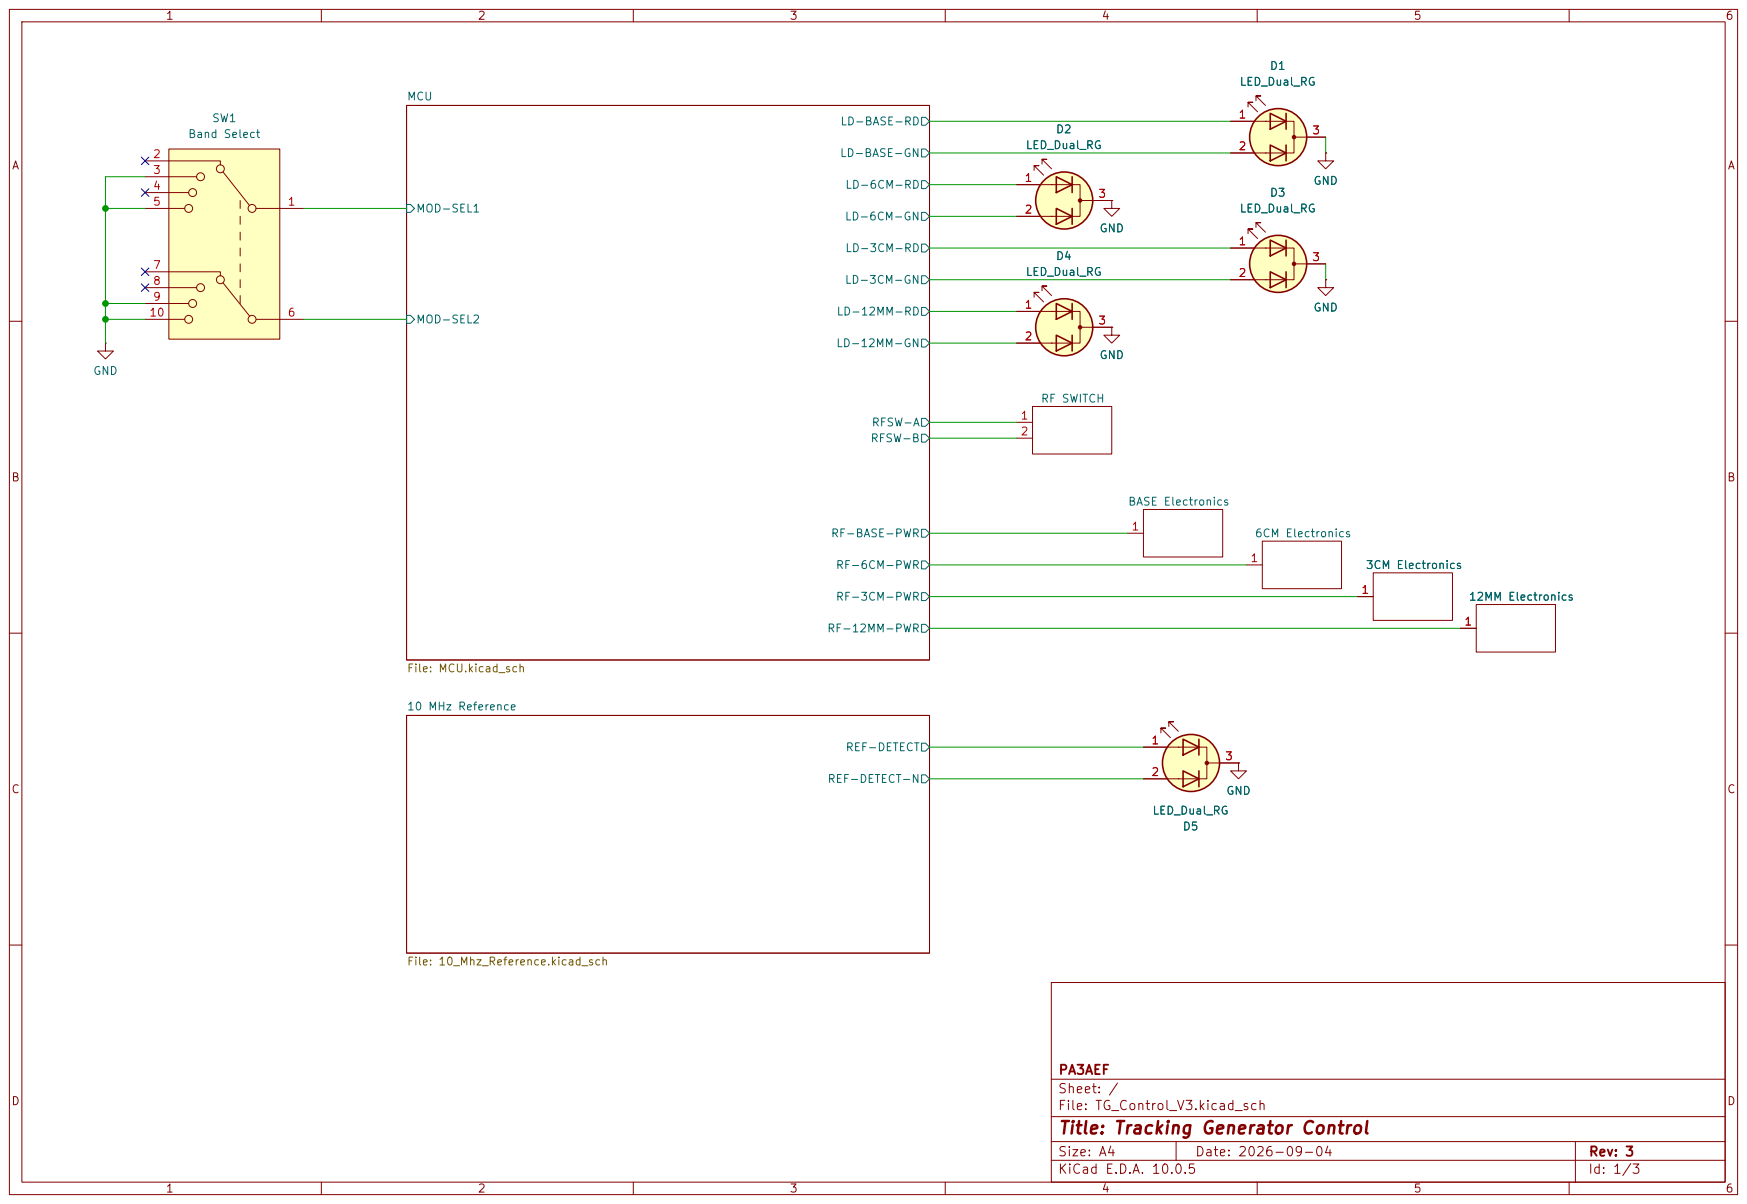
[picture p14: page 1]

REF-DETECT REF-DETECT-N

Size: A4 | Rev: 3
KiCad E.D.A. 10.0.5 | Id: 1/3

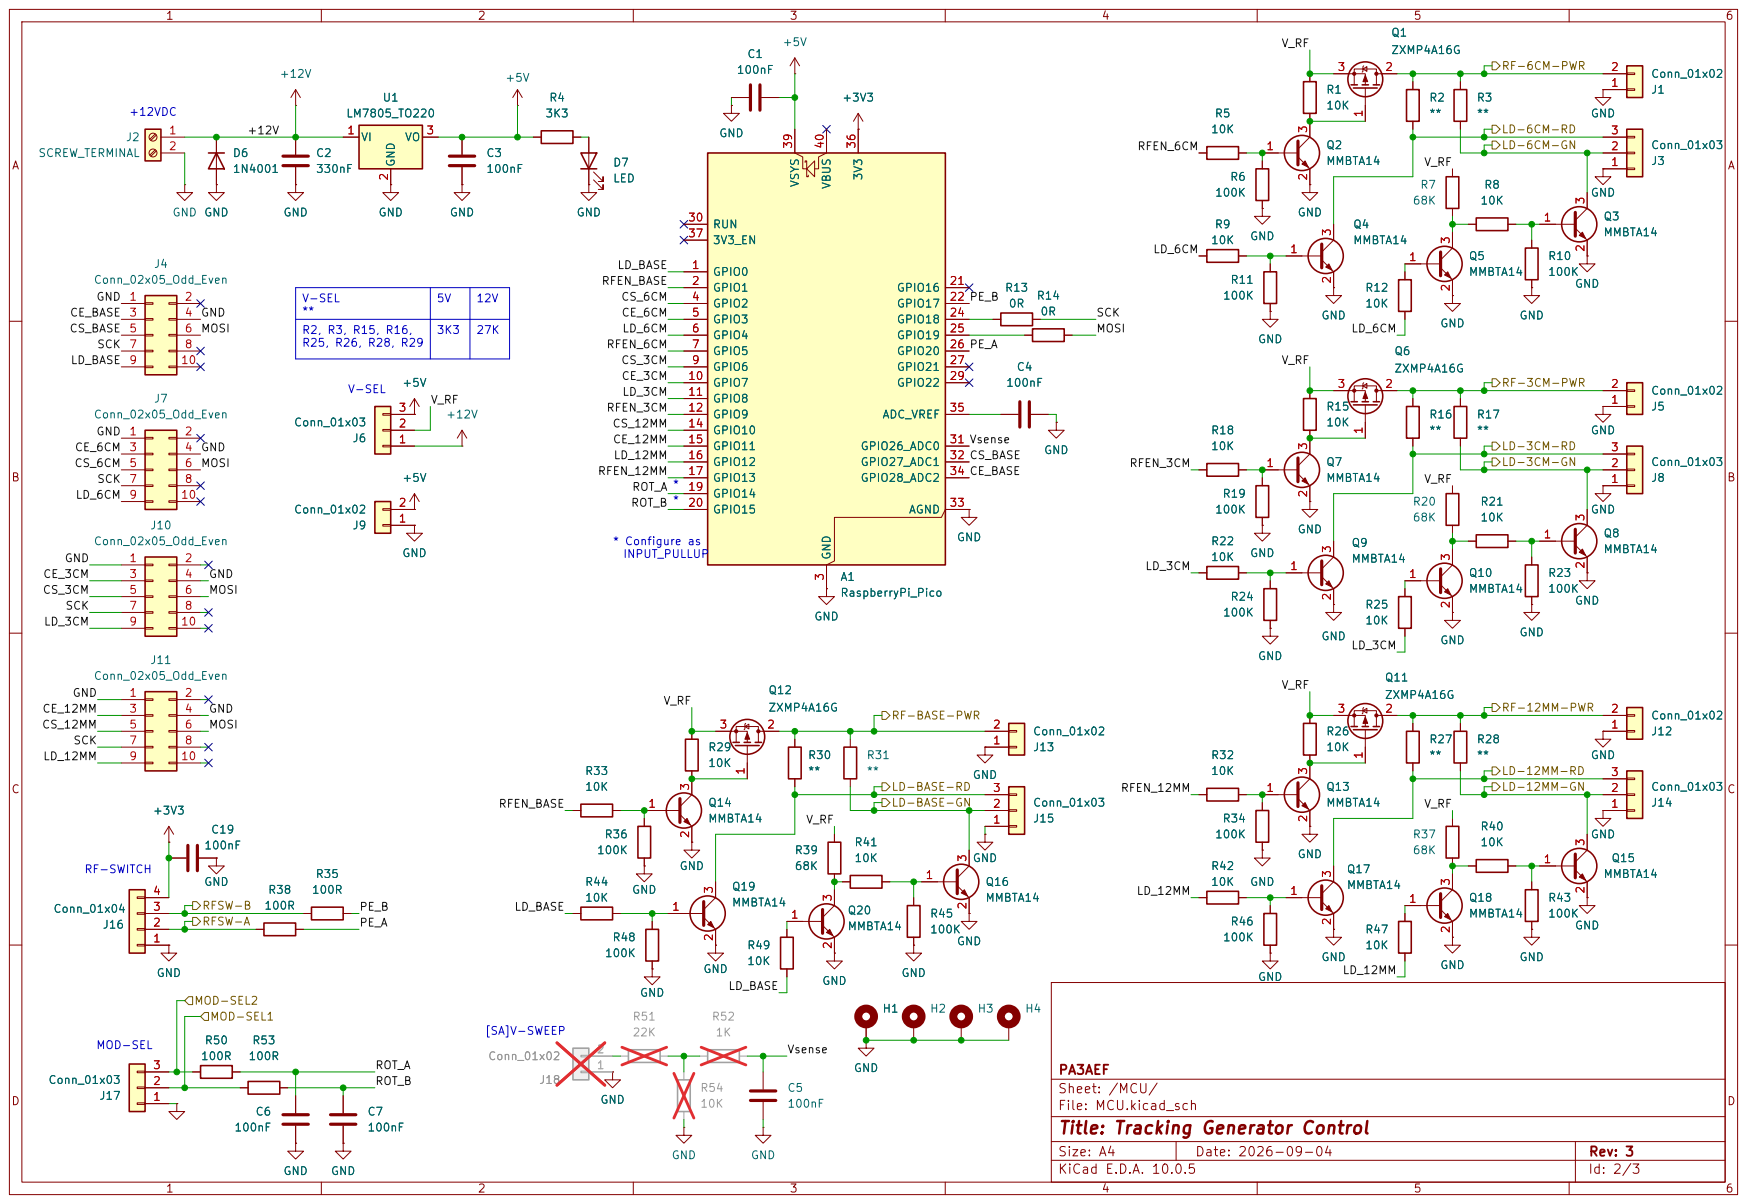
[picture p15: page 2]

V-SEL ** R3, R15, R16, | 5V | 12V R2,

LD-3CM-RD MOD-SEL1 MOD-SEL2

LD-BASE-GN 2 2

[SA]V-SWEEP MOD-SEL

PA3AEF
Sheet: /MCU/
File: MCU.kicad_sch
Title: Tracking Generator Control

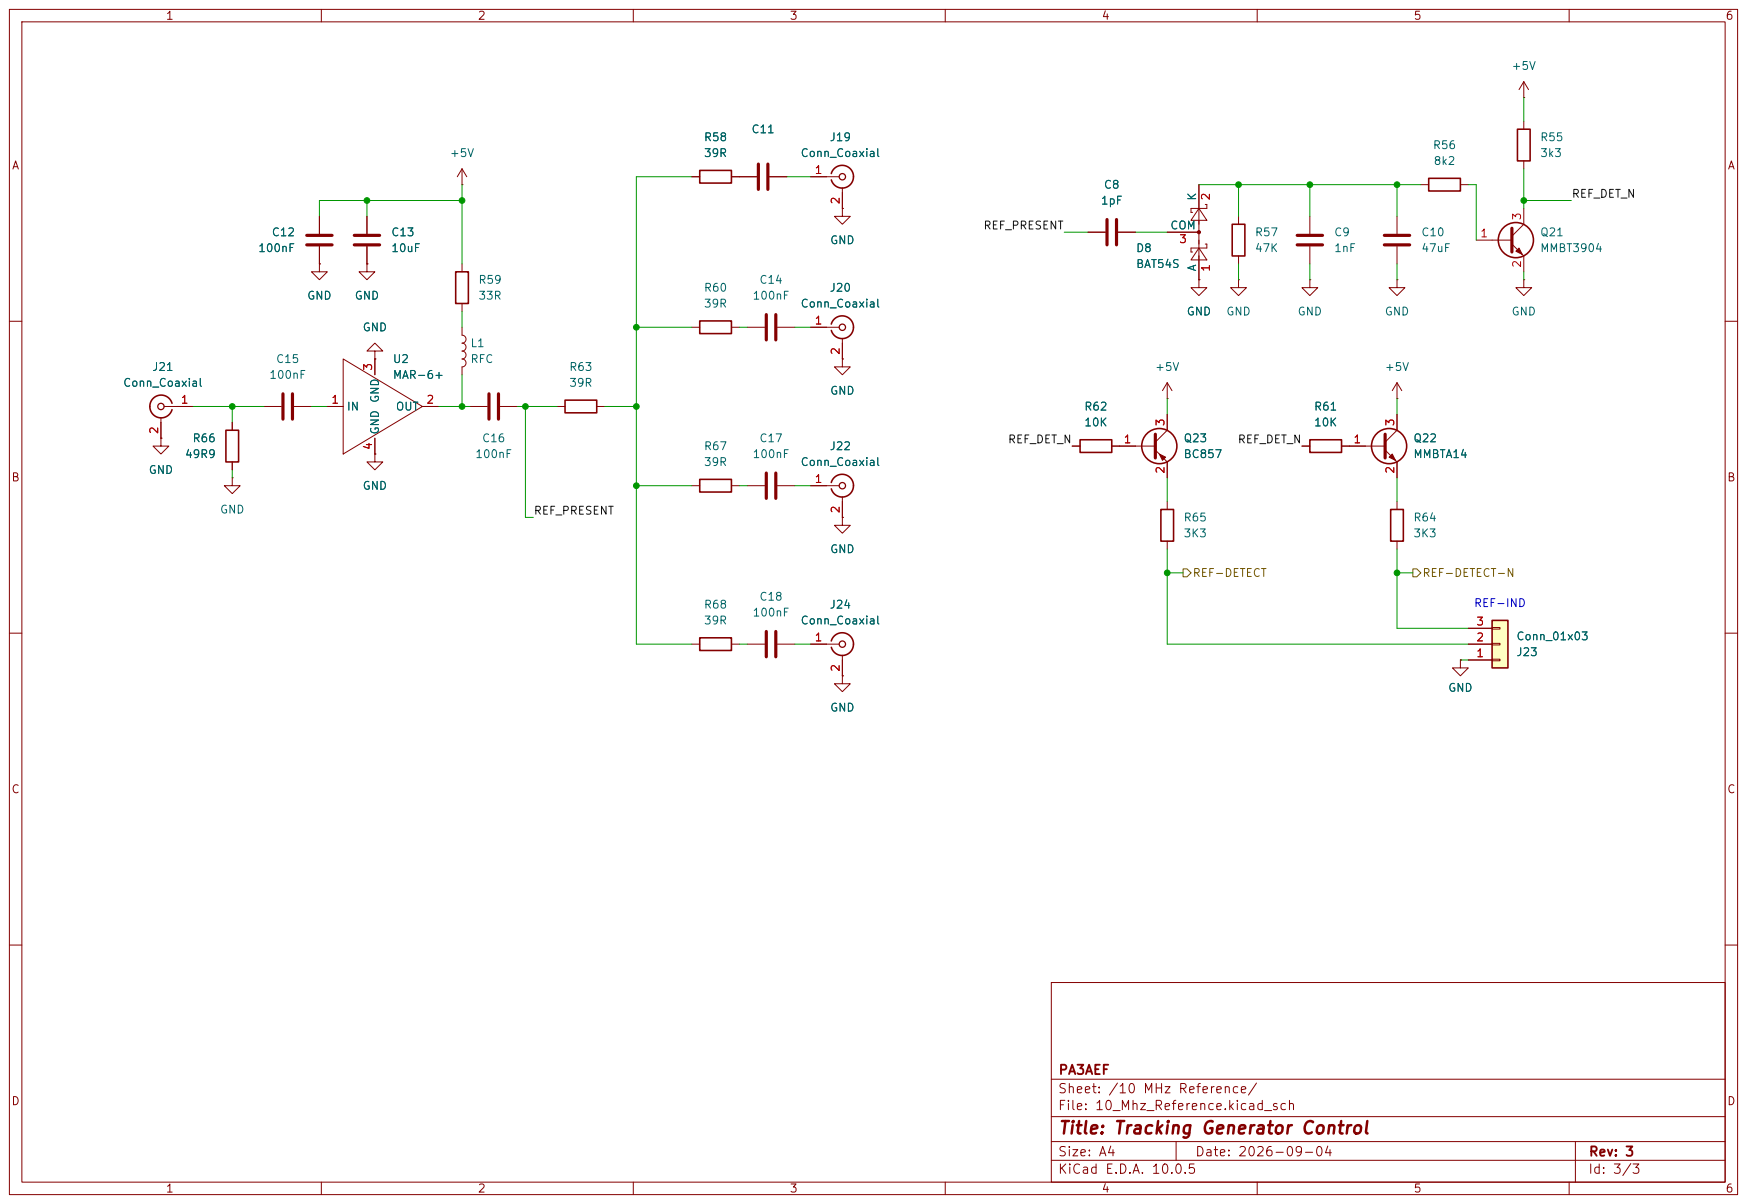
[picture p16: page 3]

PA3AEF
Sheet: /10 MHz Reference/
File: 10_Mhz_Reference.kicad_sch
Title: Tracking Generator Control

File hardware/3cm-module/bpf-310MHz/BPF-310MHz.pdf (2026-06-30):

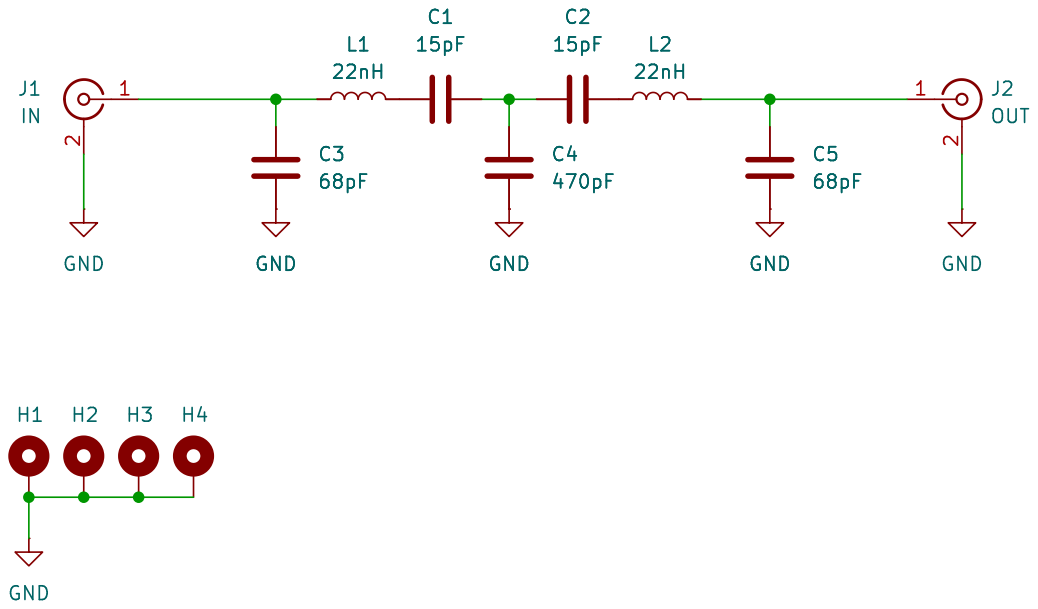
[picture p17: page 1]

310 MHz Band Pass Filter

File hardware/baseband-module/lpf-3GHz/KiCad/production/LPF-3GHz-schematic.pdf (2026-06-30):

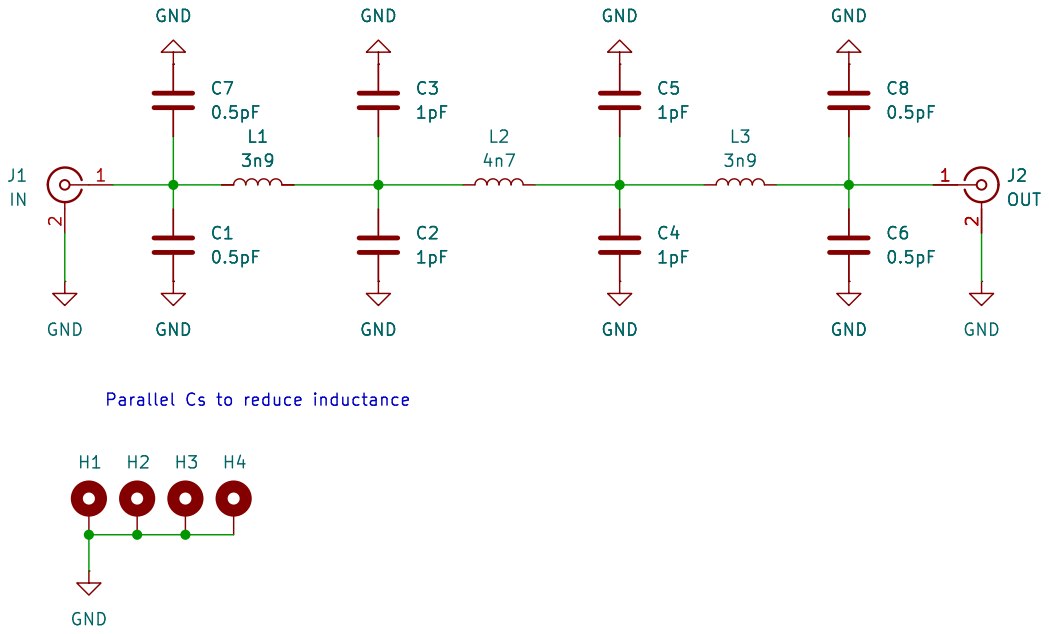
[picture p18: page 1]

Id: 1/1 Title: File: LPF-3GHz.kicad_sch Sheet: /

3 GHz Low Pass Filter

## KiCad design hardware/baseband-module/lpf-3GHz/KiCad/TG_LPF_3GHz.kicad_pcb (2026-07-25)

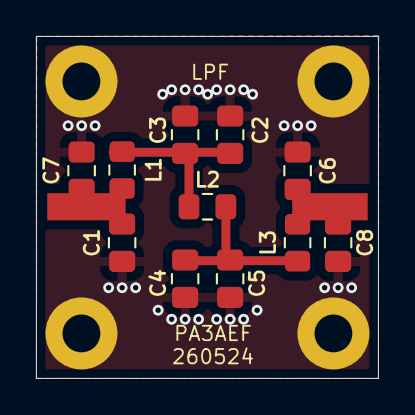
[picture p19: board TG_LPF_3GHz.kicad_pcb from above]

Board: 2 copper layers, 19.0 x 19.0 mm, 15 parts (0 on the bottom side), 5 nets.

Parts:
C1, C2, C3, C4, C5, C6: 1pF; C_0805_2012Metric_Pad1.18x1.45mm_HandSolder
C7, C8: 0pF; C_0805_2012Metric_Pad1.18x1.45mm_HandSolder
H1, H2, H3, H4: Hole_M2; MountingHole_2.1mm_M2_Pad
L1, L3: 3n9; L_0805_2012Metric_Pad1.15x1.40mm_HandSolder
L2: 4n7; L_0805_2012Metric_Pad1.15x1.40mm_HandSolder

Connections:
GND: C1.1, C2.1, C3.1, C4.1, C5.1, C6.1, C7.2, C8.2, H1.1, H2.1, H3.1, H4.1
unnamed: C1.2, C7.1, L1.1
unnamed: C2.2, C3.2, L1.2, L2.1
unnamed: C4.2, C5.2, L2.2, L3.1
unnamed: C6.2, C8.1, L3.2

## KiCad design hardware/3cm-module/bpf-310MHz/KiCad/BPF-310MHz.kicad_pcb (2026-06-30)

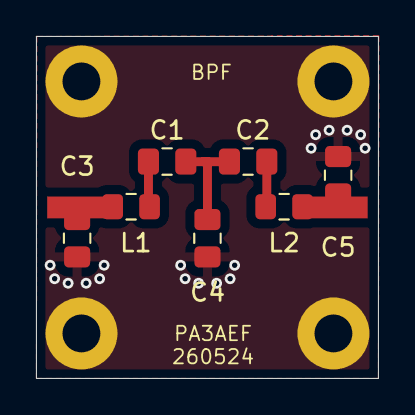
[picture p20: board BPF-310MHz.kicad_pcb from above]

Board: 2 copper layers, 19.0 x 19.0 mm, 11 parts (0 on the bottom side), 6 nets.

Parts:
C1, C2: 15pF; C_0805_2012Metric_Pad1.18x1.45mm_HandSolder
C3, C5: 68pF; C_0805_2012Metric_Pad1.18x1.45mm_HandSolder
C4: 470pF; C_0805_2012Metric_Pad1.18x1.45mm_HandSolder
H1, H2, H3, H4: Hole_M2; MountingHole_2.1mm_M2_Pad
L1, L2: 22nH; L_0805_2012Metric_Pad1.15x1.40mm_HandSolder

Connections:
GND: C3.1, C4.1, C5.1, H1.1, H2.1, H3.1, H4.1
unnamed: C1.1, C2.2, C4.2
unnamed: C1.2, L1.2
unnamed: C2.1, L2.1
unnamed: C3.2, L1.1
unnamed: C5.2, L2.2

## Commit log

2026-06-30 Refactor code structure for improved readability and maintainability
    [BPF-310MHz.kicad_pcb, BPF-310MHz.kicad_sch, LPF-3GHz.kicad_pcb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]
2026-07-25 Add positions CSV file for control module components in KiCad
    [10_Mhz_Reference.kicad_sch, MCU.kicad_sch, TG_LPF_3GHz.kicad_pcb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]
2026-07-26 Add fabrication toolkit options, production files, and netlist for LPF 12GHz module
    - Created fabrication-toolkit-options.json with default settings.
    - Added TG_LPF_12GHz.zip containing production files including copper, mask, paste, silkscreen, edge cuts, and netlist.
    - Introduced designators.csv for component designators in the production.
    - Added netlist.ipc for IPC netlist representation of the LPF 12GHz module.
    [TG_LPF_12GHz.kicad_pcb, TG_LPF_12GHz.kicad_sch, designators.csv]
2026-07-26 Update frequency ranges for 6 cm and 3 cm modules in README
2026-07-27 Updated control board PCB
2026-08-10 Rethinking LO distribution. With a PE42540 SP4T RF Switch an amplifier might not be needed
2026-08-14 Adjust LO module hardware to low-loss switch
2026-09-01 Rearanged 10 MHz reference circuit. OPA chip did not do the job. Changed to a 50 ohm passive resistor network driven by a MAR-6
    Changed band control to include proper LED signaling
    [10_Mhz_Reference.kicad_sch, MCU.kicad_sch, TG_control.kicad_pcb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]
2026-09-04 modified: hardware/control-module/KiCad/production/TG_Control_V3.zip modified: hardware/control-module/KiCad/production/netlist.ipc modified: hardware/control-module/KiCad/production/positions.csv mo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
    [positions.csv]
2026-09-27 Refactor 10 MHz reference distribution design to replace op-amp buffer with broadband MMIC amplifier for improved gain, impedance control, and RF integrity.
2026-09-27 Update project status in README with new PCB development and completion of LO distribution and Base-Band module
2026-09-27 Update README with project status and firmware testing details for MCU board
2026-10-06 Updated PCB. 1) +12V output for auxilary circuits 2) Replaced OPA buffer with MMIC
2026-10-19 Add Tracking Generator firmware for Raspberry Pi PICO
    - Implemented main control logic in Tracking_Generator_V6.ino to manage PLL synthesizers and RF routing.
    - Created bands management in bands.cpp, bands.h to define band configurations and enable/disable bands.
    - Added PE42540 switch control in pe42540.cpp and pe42540.h for RF routing.
    - Developed PLL control logic in pll_control.cpp and pll_control.h to abstract PLL operations for MAX2870 and ADF4351.
    - Introduced ADF4351 and MAX2870 drivers in pll_adf4351.cpp, pll_adf4351.h, pll_max2870.cpp, and pll_max2870.h for frequency setting and register management.
    - Implemented rotary switch handling in rotary.cpp and rotary.h for band selection.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
2026-10-19 Refactor firmware structure and implement new PLL control system
    - Removed obsolete MAX2870 and ADF4351 header and source files.
    - Consolidated PLL control logic into a unified API for easier management of PLL devices.
    - Introduced new source files for handling band configurations and RF routing.
    - Added rotary switch functionality for band selection with debounce logic.
    - Implemented ramp generation for frequency control based on band settings.
    - Established a new pin configuration header for better hardware abstraction.
    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
2026-10-20 Add blank line before "Power distribution & LO levels" section in system architecture documentation
2026-10-20 Fix image filename case in system architecture documentation
